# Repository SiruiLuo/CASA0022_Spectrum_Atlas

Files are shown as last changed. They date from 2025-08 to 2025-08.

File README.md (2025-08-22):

# 🌐 Spectrum Atlas - A Wireless Signal Detection & Visualization System

    

## 📖 Project Overview

Spectrum Atlas is a comprehensive wireless signal spectrum mapping and visualization system that integrates hardware and software technologies to generate 2D and 3D heatmaps of wireless signals in spatial environments, providing professional solutions for spectrum analysis, signal monitoring, and visualization applications.

<div align="center">

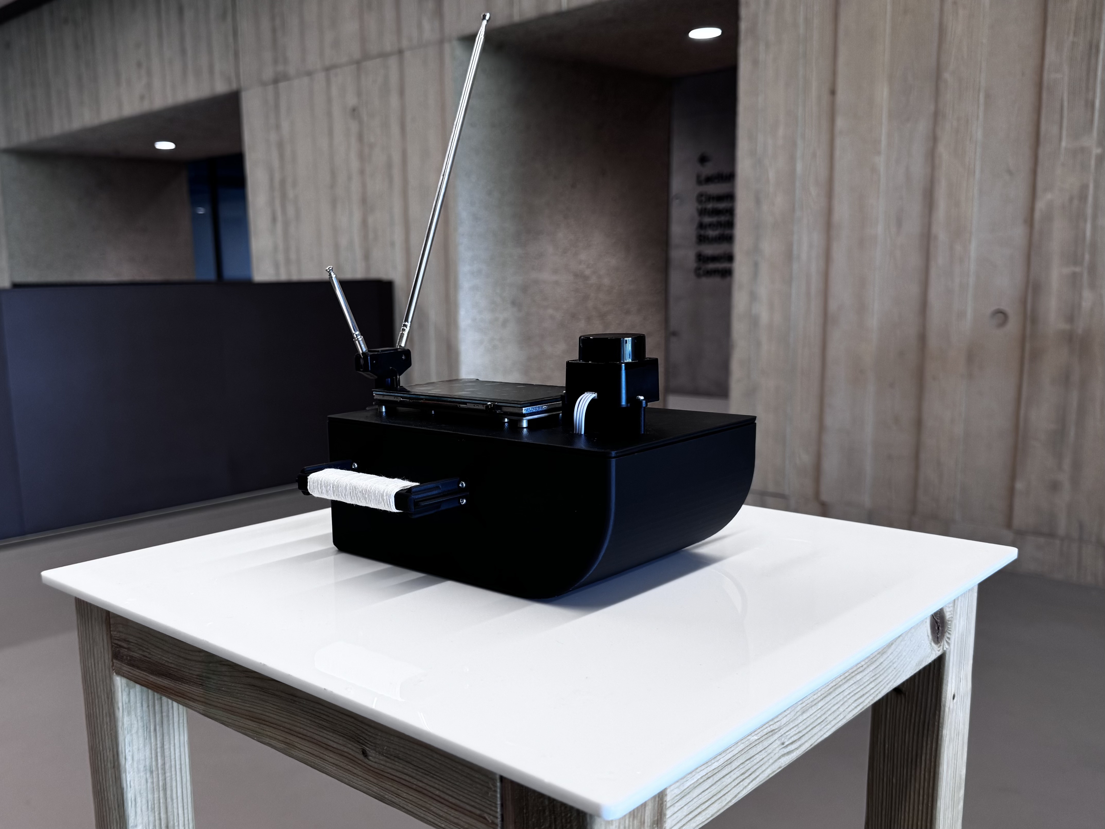
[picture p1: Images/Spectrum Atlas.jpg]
Spectrum Atlas System


**Figure 1: Spectrum Atlas System Overview**

</div>

### 🎥 Official Demo Video
<div align="center">



</div>

## ✨ Core Features

- 🎯 **Multi-band Signal Scanning**: Supports automatic scanning of multiple frequency bands from 27MHz to 1800MHz
- 📍 **Spatial Positioning**: Each sampling point contains precise 2D coordinate information
- 💾 **Data Persistence**: PostgreSQL database storage with multi-session management support
- 🗺️ **Heatmap Generation**: RBF interpolation + Gaussian filtering + visualization rendering
- 🔄 **Batch Processing**: Full frequency band batch output supporting multiple signal types
- 🌐 **Cross-device Collaboration**: Raspberry Pi generation → Local download viewing
- 🖥️ **Interactive Web Interface**: Real-time heatmap visualization with hover information display
- 📊 **Dynamic Data Loading**: Real-time database integration for live data access

## 🏗️ System Architecture

### Hardware Platform
- **Raspberry Pi 4 Model B**: Main control device responsible for running ROS, signal scanning, data storage, and image rendering
- **FHL-LD19 LiDAR**: For obtaining spatial shape and distance information, generating spatial maps, and 2D plane mapping construction
- **RTL-SDR Blog V4**: For acquiring signal strength (RSSI) at different frequency bands from 1 MHz to 1.78 GHz
- **Waveshare 5-inch Touch Display**: For graphical user interface display and user interaction

<div align="center">

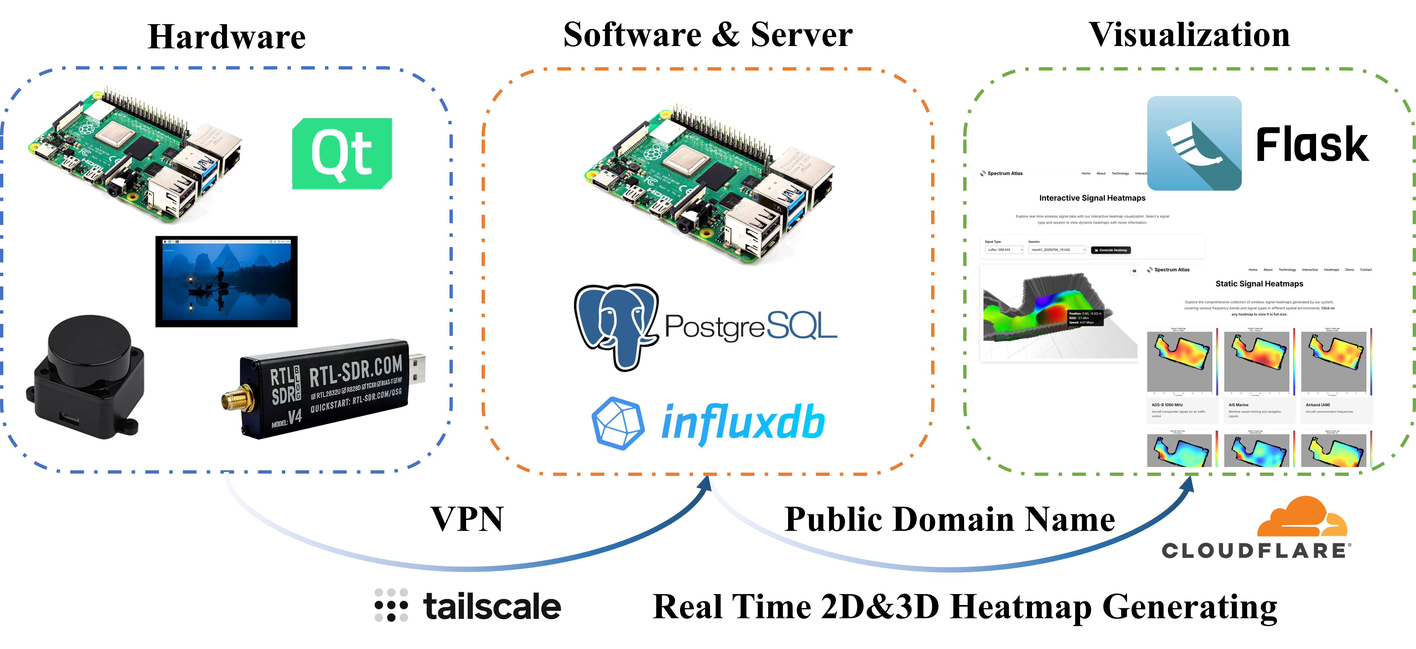
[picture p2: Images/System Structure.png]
System Structure


**Figure 2: System Architecture Structure**

</div>

### Software Architecture
- **ROS (Robot Operating System)**: Robot operating system for hardware control and data management
- **Qt GUI**: C++ desktop application providing user interaction interface
- **Flask Web Server**: Python web framework providing backend API services
- **PostgreSQL**: Relational database for signal data storage
- **LiDAR SLAM**: Uses Hector SLAM for environmental map construction

### Circuit Diagram
<div align="center">

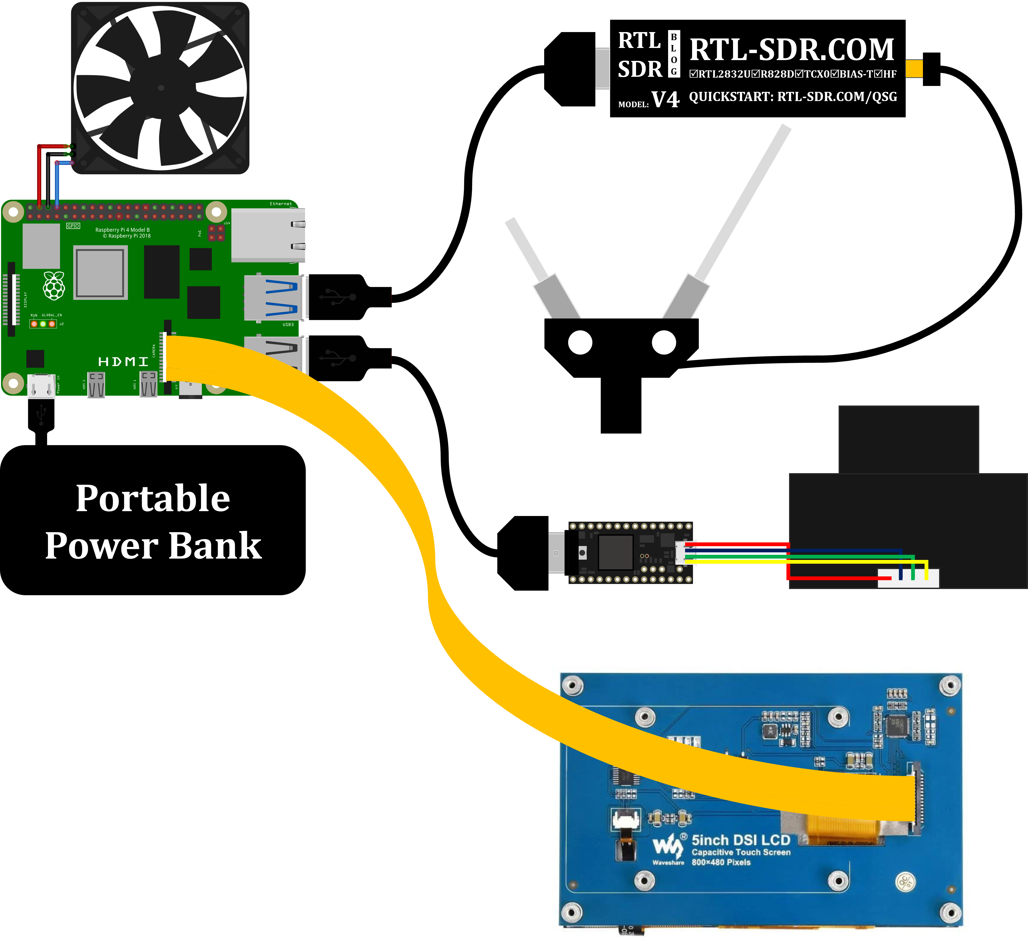
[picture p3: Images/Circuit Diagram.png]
Circuit Diagram


**Figure 3: System Circuit Diagram**

</div>

## 🔧 Technical Features

### Supported Signal Types
- **RC Low Band** (27-28 MHz): Toy remote control low frequency band
- **RC Aircraft** (35-36 MHz): UK RC aircraft dedicated frequency band
- **RC Ground** (40-41 MHz): UK RC car/boat remote control frequency band
- **TETRA / Emergency** (380-400 MHz): Police/fire/emergency communications
- **LoRa / ISM 433** (433-434 MHz): LoRa, RF remotes, access control
- **ISM 868** (868-870 MHz): LoRaWAN, Sigfox, NB-IoT, metering
- **GSM 900 UL** (880-915 MHz): User uplink channels (mobile device → base station)
- **GSM 900 DL** (925-960 MHz): Downlink channels (base station → mobile device)
- **FM Radio** (88-108 MHz): FM broadcast
- **Airband (AM)** (118-137 MHz): Pilot communications (AM)
- **AIS / Marine** (161-163 MHz): Maritime automatic identification system
- **ADS-B 1090** (1090 MHz): Aircraft broadcast position
- **LTE 1800** (1710-1760 MHz): LTE user uplink

### Algorithm Flow

#### Fixed-Parameter RBF-Gaussian Heatmap Algorithm (FPRGH) 
<div align="center">

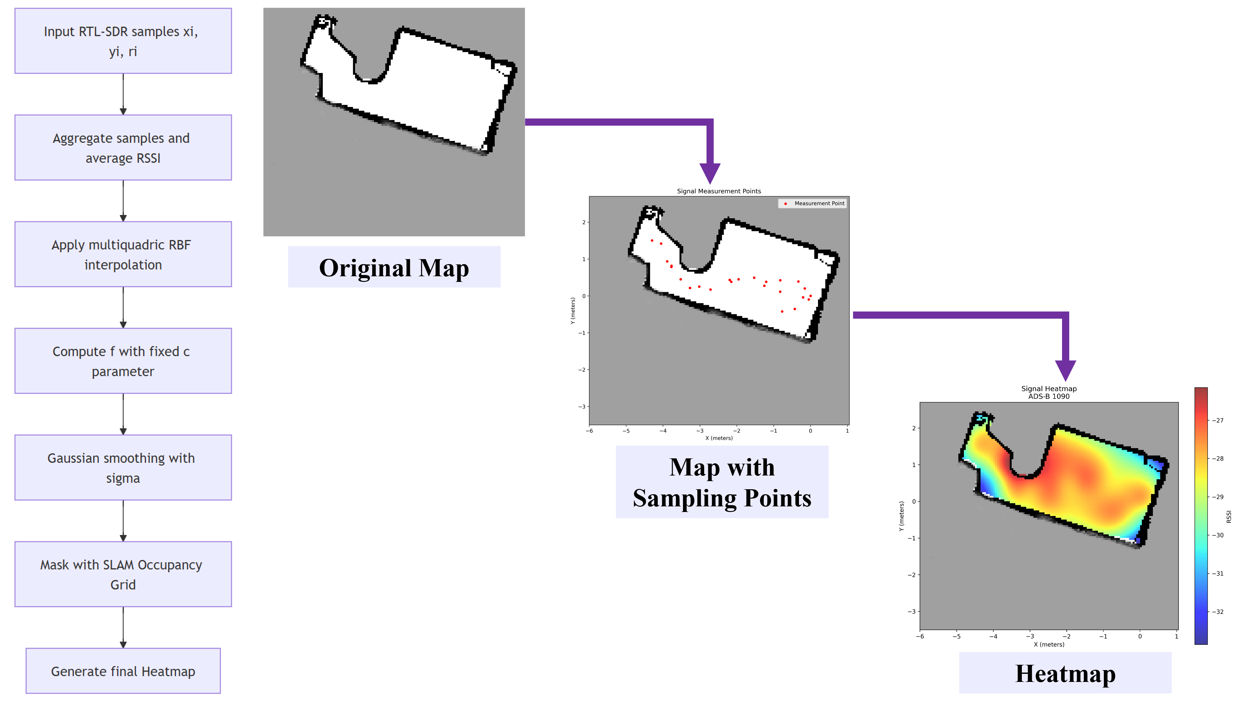
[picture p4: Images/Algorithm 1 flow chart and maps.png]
Algorithm 1


**Figure 4: Algorithm 1 - Map Construction and Data Acquisition**

</div>

#### Adaptive RBF Heatmap Algorithm with Spatial Scaling (ARH-SS)
<div align="center">

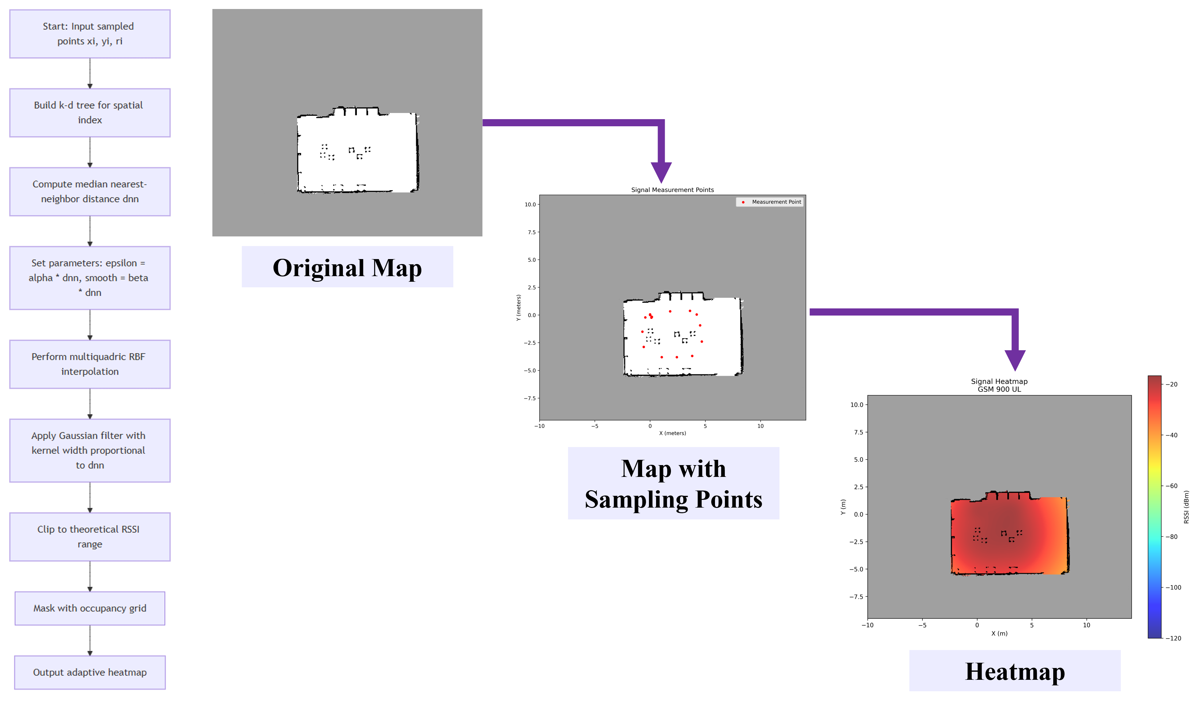
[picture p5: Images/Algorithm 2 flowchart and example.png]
Algorithm 2


**Figure 5: Algorithm 2 - Heatmap Generation and Visualization**

</div>

## 📁 Project Structure

```
CASA0022_Spectrum_Atlas/
├── 3D Models/                    # 3D printed model files
├── Detector/                     # Detector related code
│   ├── ble_scan.py              # BLE signal scanning
│   ├── ldlidar_ros_ws/         # LiDAR ROS workspace
│   └── ros_catkin_ws/          # ROS Catkin workspace
├── Spectrum_Atlas_GUI/          # Qt GUI application
├── Server and Database/         # Server and database
│   ├── Database/               # Database scripts and API
│   └── Flask Server/           # Flask web server
├── Wireless Signal Dataset/     # Wireless signal dataset
└── Images/                     # Project images and charts
```

## 🚀 Quick Start

### Requirements
- **Operating System**: Ubuntu 18.04+ / Raspberry Pi OS
- **Python**: 3.8+
- **ROS**: Melodic (recommended)
- **Qt**: 5.12+
- **Database**: PostgreSQL 12+

### Installation Steps

1. **Clone the Project**
```bash
git clone https://github.com/SiruiLuo/CASA0022_Spectrum_Atlas.git
cd CASA0022_Spectrum_Atlas
```

2. **Install ROS Dependencies**
```bash
# Install ROS Melodic
sudo apt update
sudo apt install ros-melodic-desktop-full

# Initialize ROS workspace
cd Detector/ros_catkin_ws
catkin_make
source devel/setup.bash
```

3. **Install Python Dependencies**
```bash
cd Server and Database/Flask Server/Spectrum_Atlas_Webpage-main
python -m venv spectrum_env
source spectrum_env/bin/activate  # Linux/Mac
# or
spectrum_env\Scripts\activate     # Windows

pip install -r requirements.txt
```

4. **Configure Database**
```bash
# Install PostgreSQL
sudo apt install postgresql postgresql-contrib

# Create database and user
sudo -u postgres psql
CREATE DATABASE spectrum_atlas;
CREATE USER spectrum_user WITH PASSWORD 'your_password';
GRANT ALL PRIVILEGES ON DATABASE spectrum_atlas TO spectrum_user;
\q
```

5. **Compile Qt Application**
```bash
cd Spectrum_Atlas_GUI
qmake
make
```

## 📊 Usage Examples

### Signal Acquisition
The system can automatically scan multiple frequency bands and generate heatmaps:

#### Student Dormitory Signal Heatmaps (2025-07-09)
All frequency band heatmaps generated from student dorm collection:

**Low Frequency Bands:**

<div align="center">

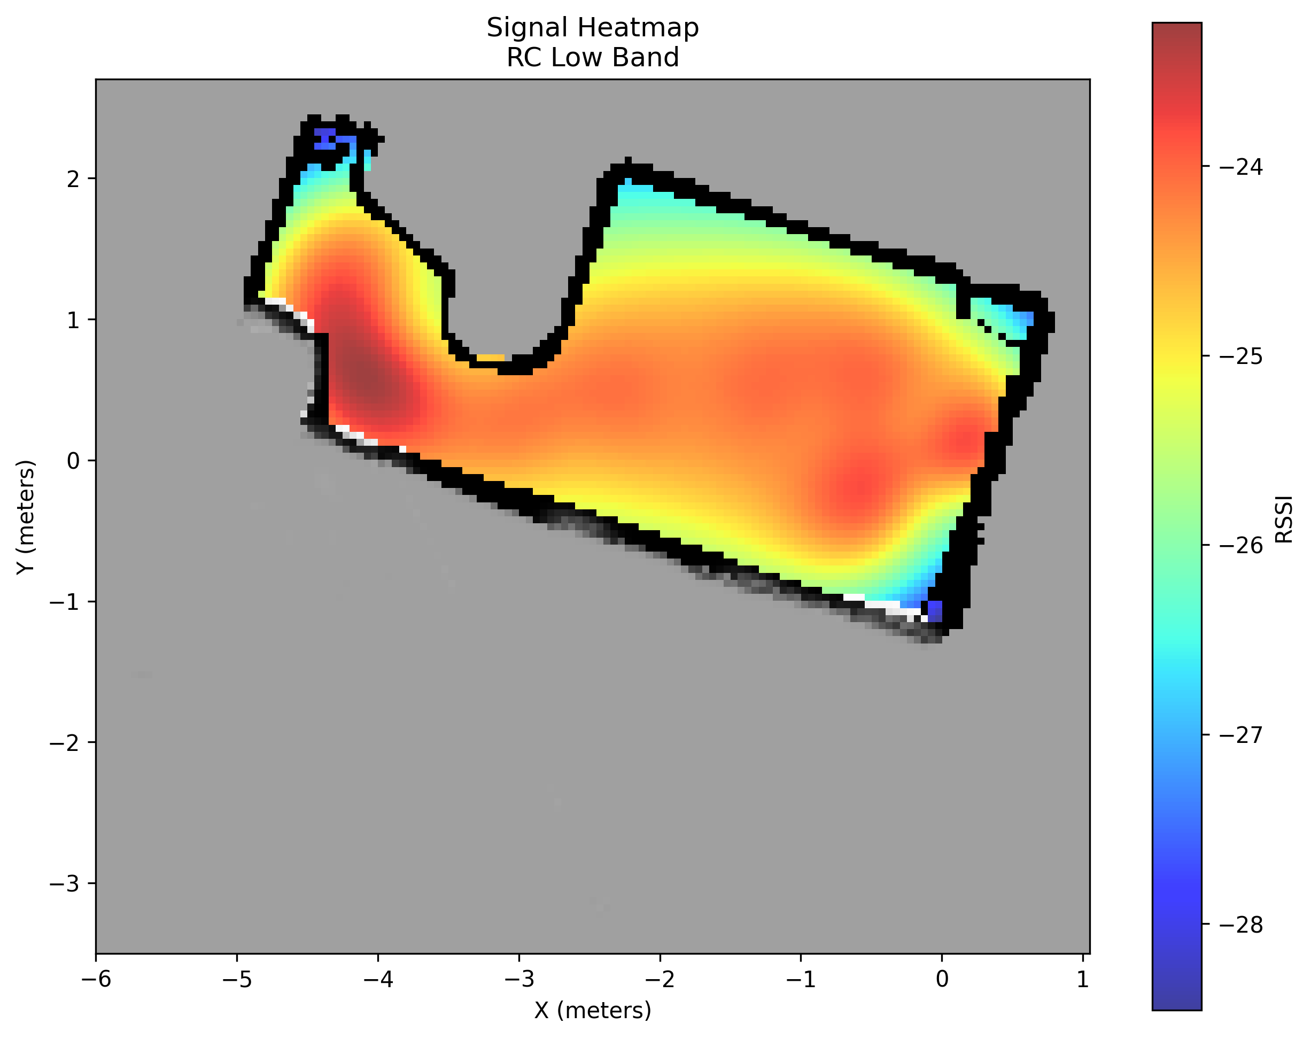
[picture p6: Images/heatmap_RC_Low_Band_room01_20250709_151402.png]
RC Low Band
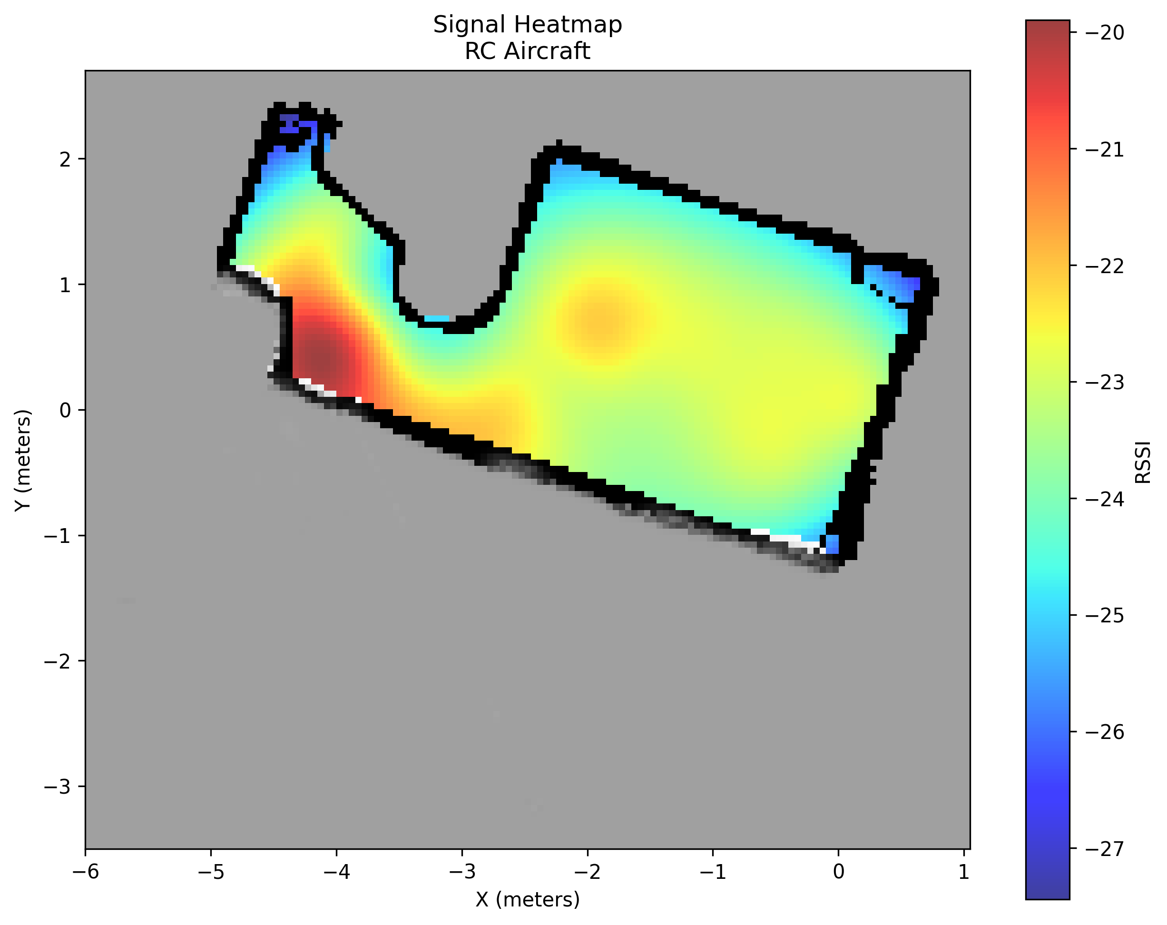
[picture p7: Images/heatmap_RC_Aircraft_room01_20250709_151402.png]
RC Aircraft
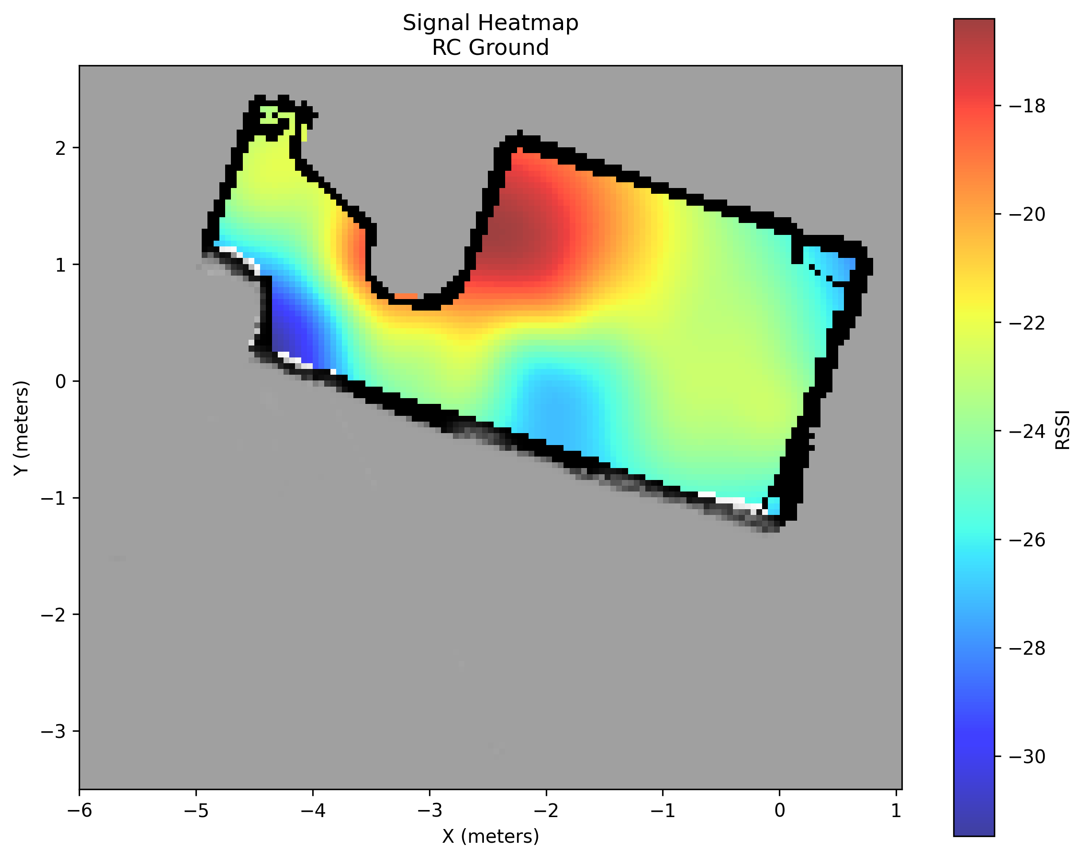
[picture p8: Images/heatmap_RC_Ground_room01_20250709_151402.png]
RC Ground
  

</div>

**Medium Frequency Bands:**

<div align="center">

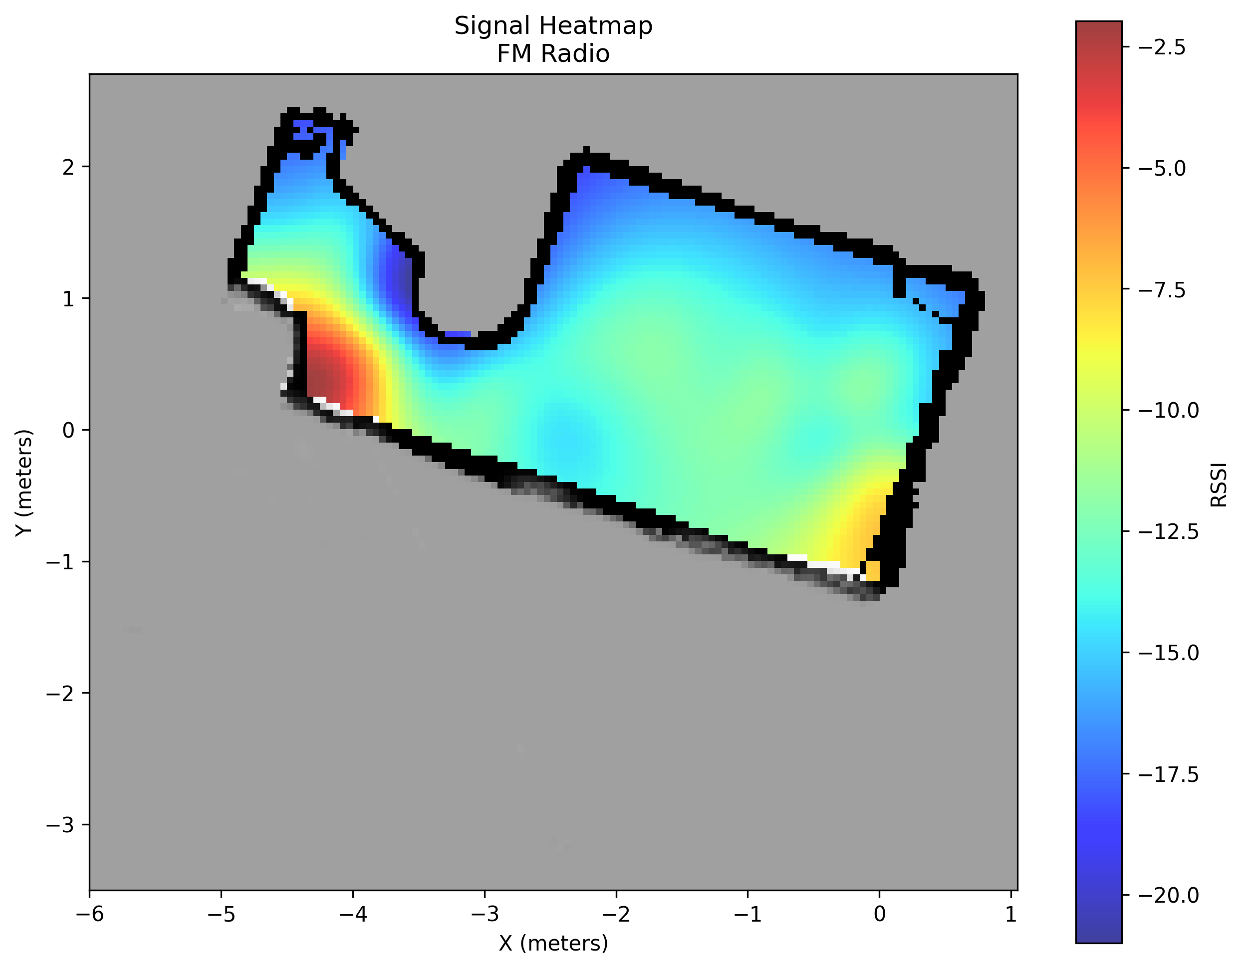
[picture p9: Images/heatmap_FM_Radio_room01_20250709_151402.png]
FM Radio
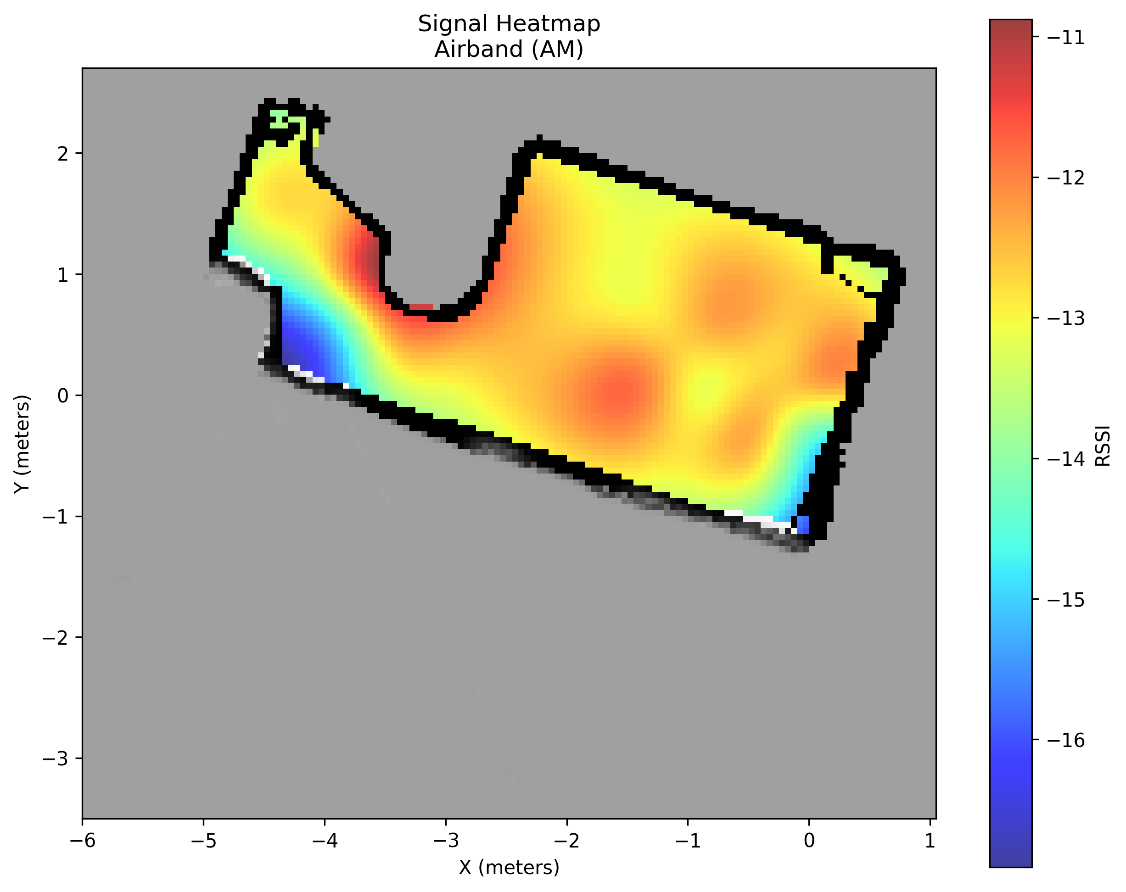
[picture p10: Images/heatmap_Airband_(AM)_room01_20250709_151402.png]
Airband AM
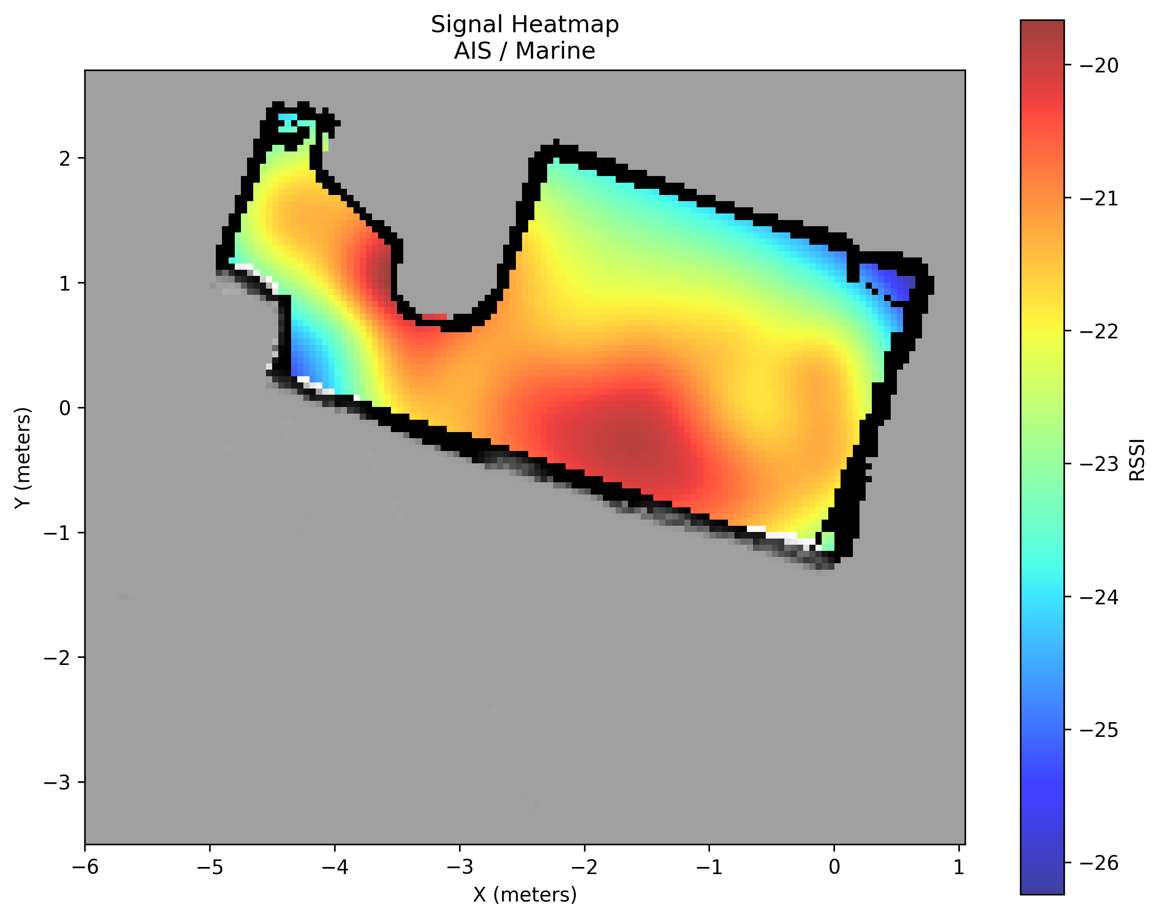
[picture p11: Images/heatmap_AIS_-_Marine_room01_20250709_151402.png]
AIS Marine
  

</div>

**High Frequency Bands:**

<div align="center">

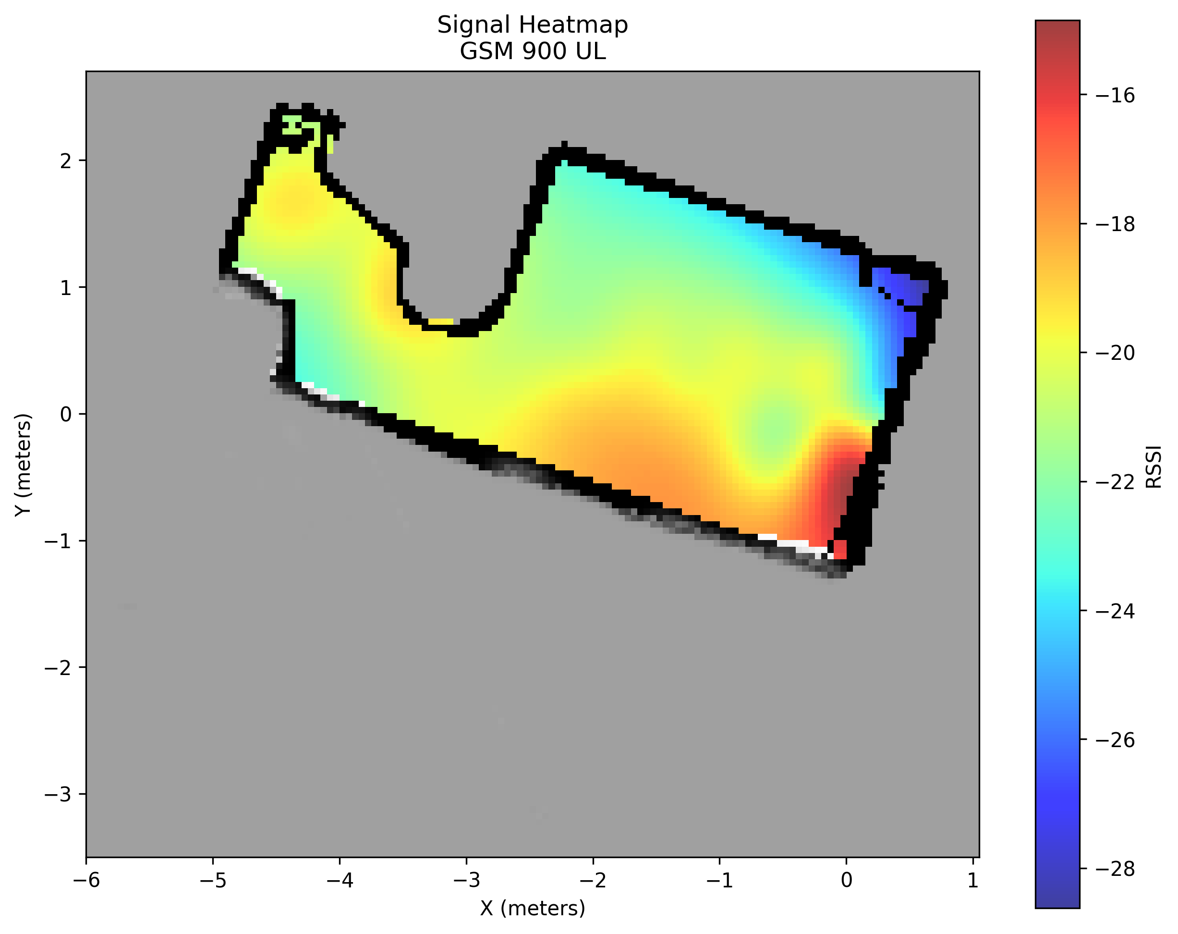
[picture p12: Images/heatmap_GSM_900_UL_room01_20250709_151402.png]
GSM 900 UL
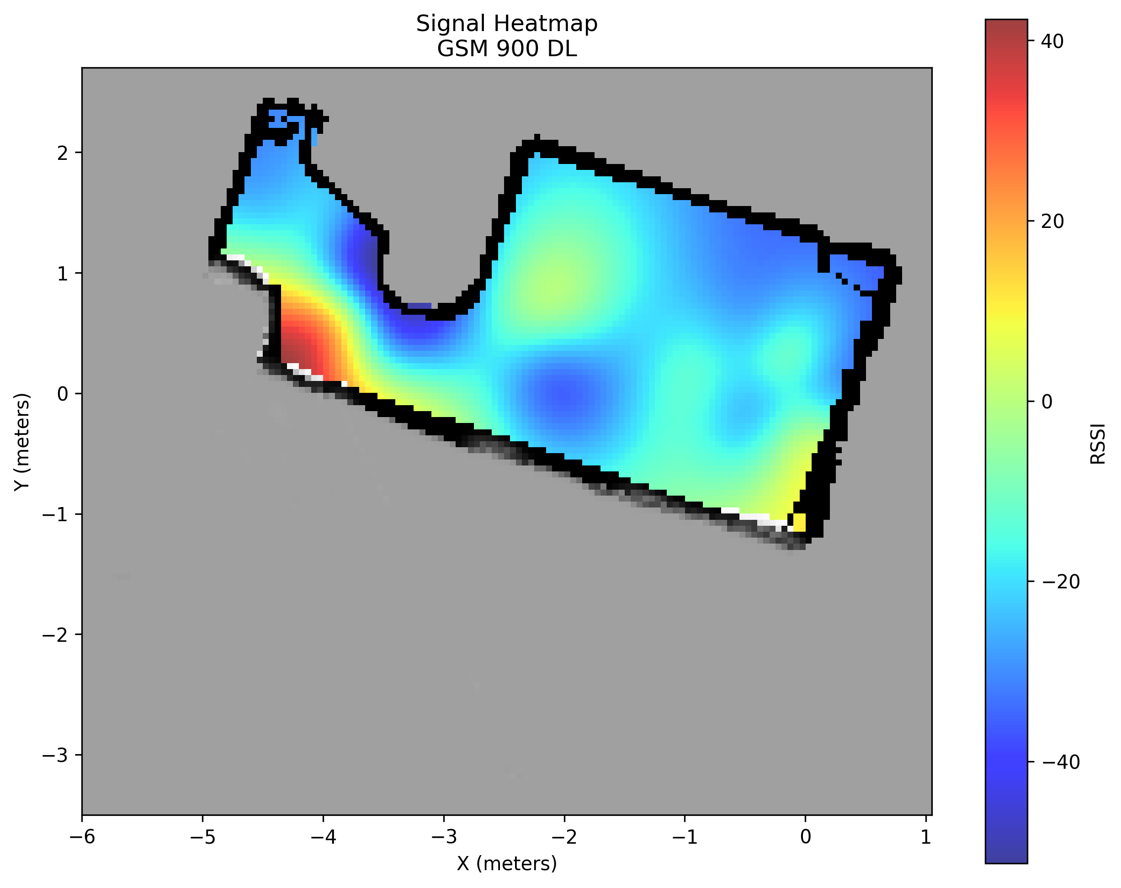
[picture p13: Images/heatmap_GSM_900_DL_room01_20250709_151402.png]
GSM 900 DL
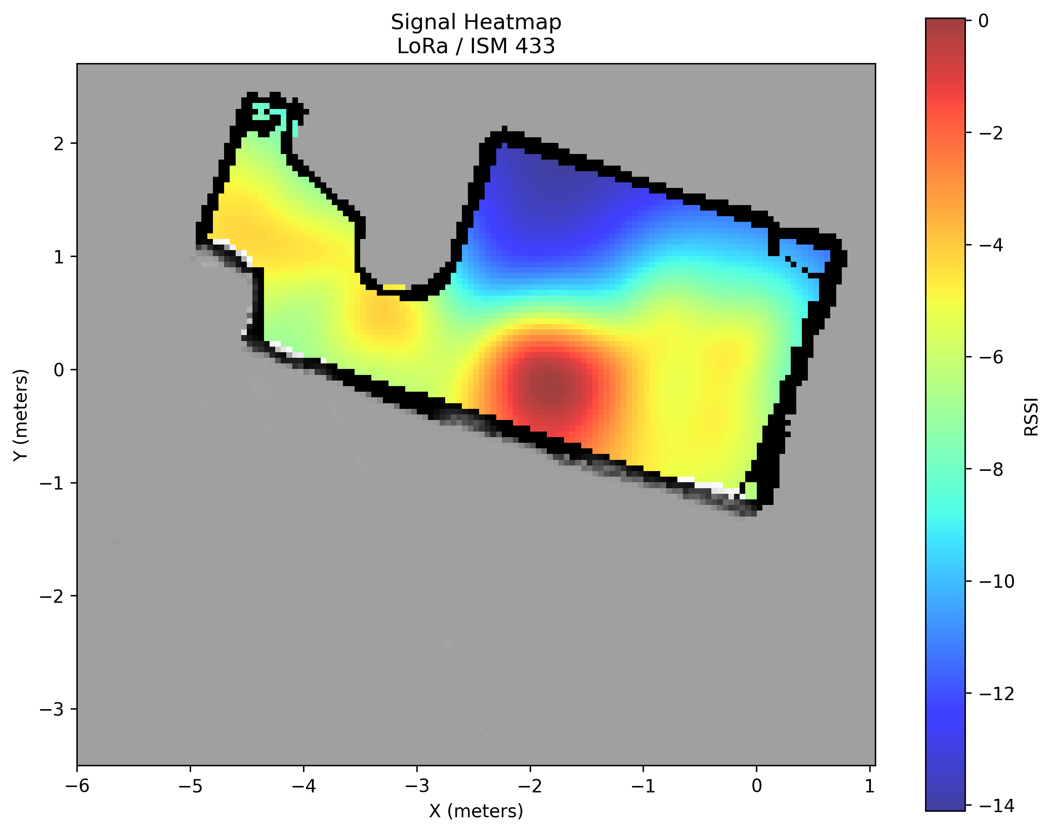
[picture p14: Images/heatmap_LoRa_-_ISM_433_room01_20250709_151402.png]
LoRa ISM 433
  

</div>

**Ultra High Frequency Bands:**

<div align="center">

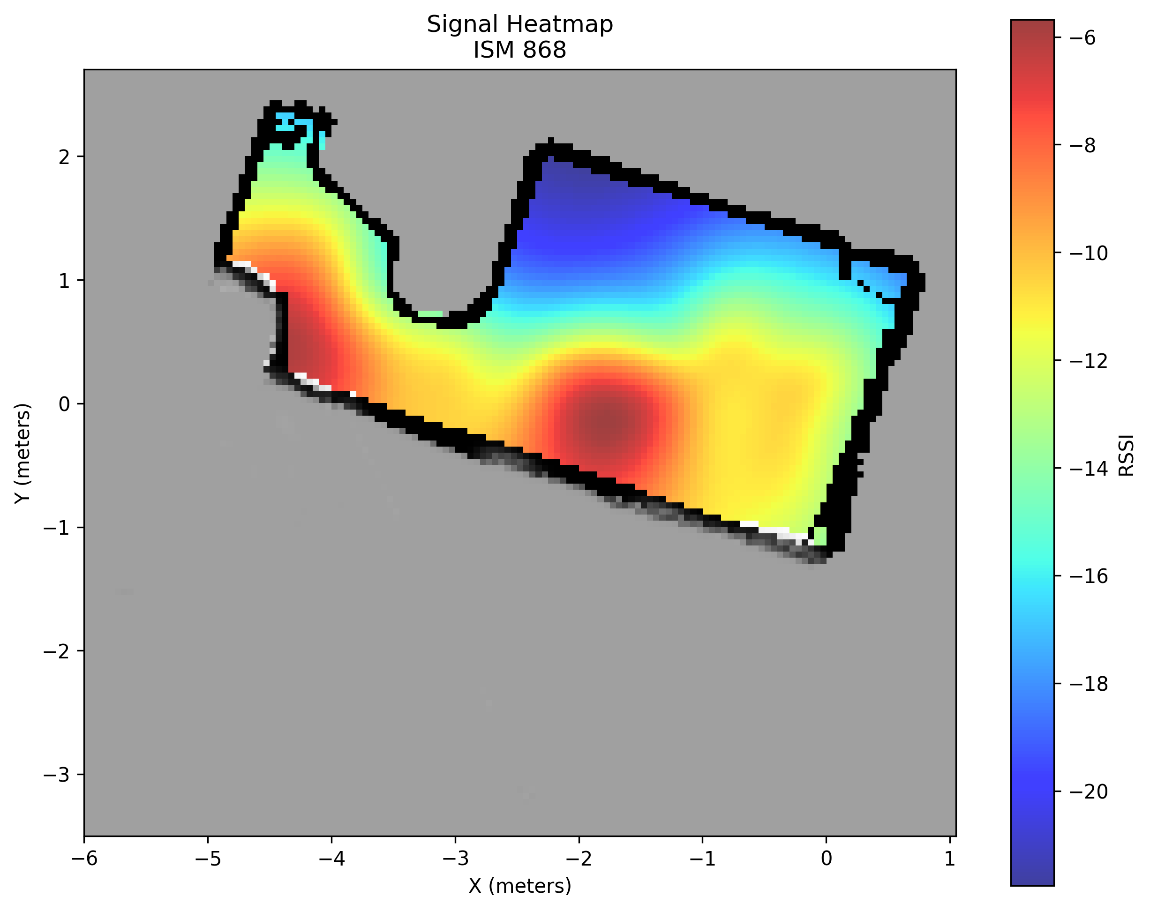
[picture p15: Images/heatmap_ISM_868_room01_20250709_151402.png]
ISM 868
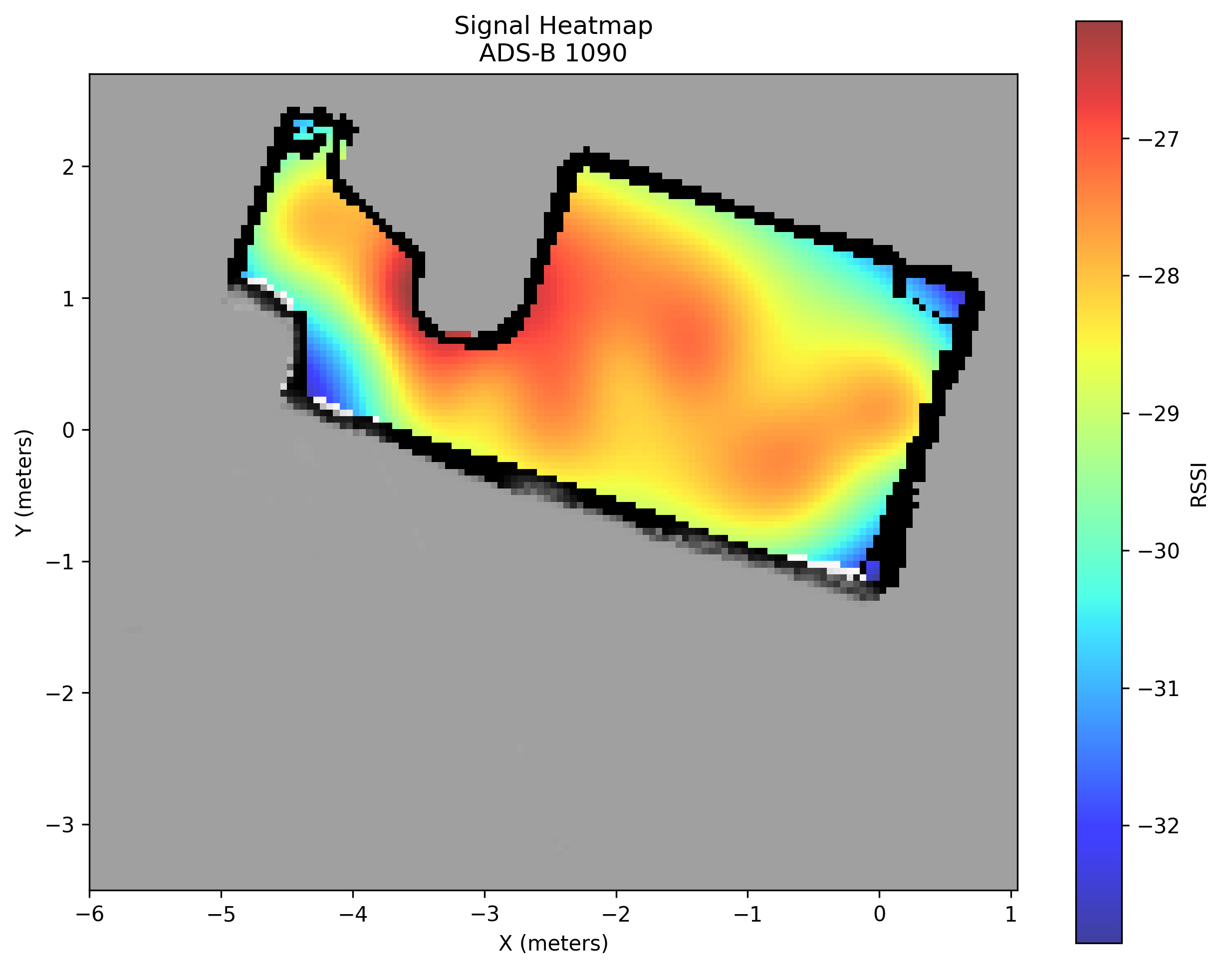
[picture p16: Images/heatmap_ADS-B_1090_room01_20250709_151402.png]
ADS-B 1090
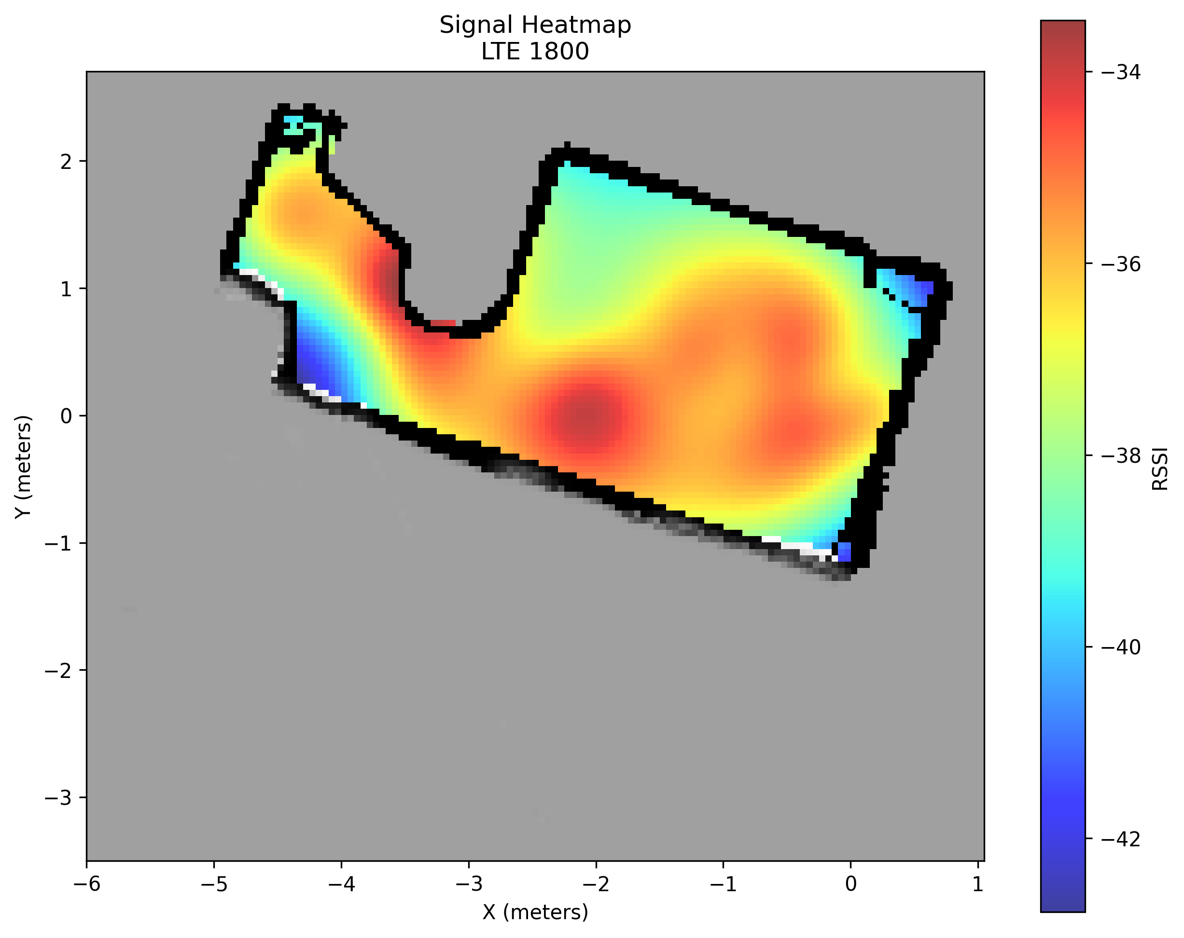
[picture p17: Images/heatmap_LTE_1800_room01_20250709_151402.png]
LTE 1800
  

</div>

**Emergency & Special Bands:**

<div align="center">

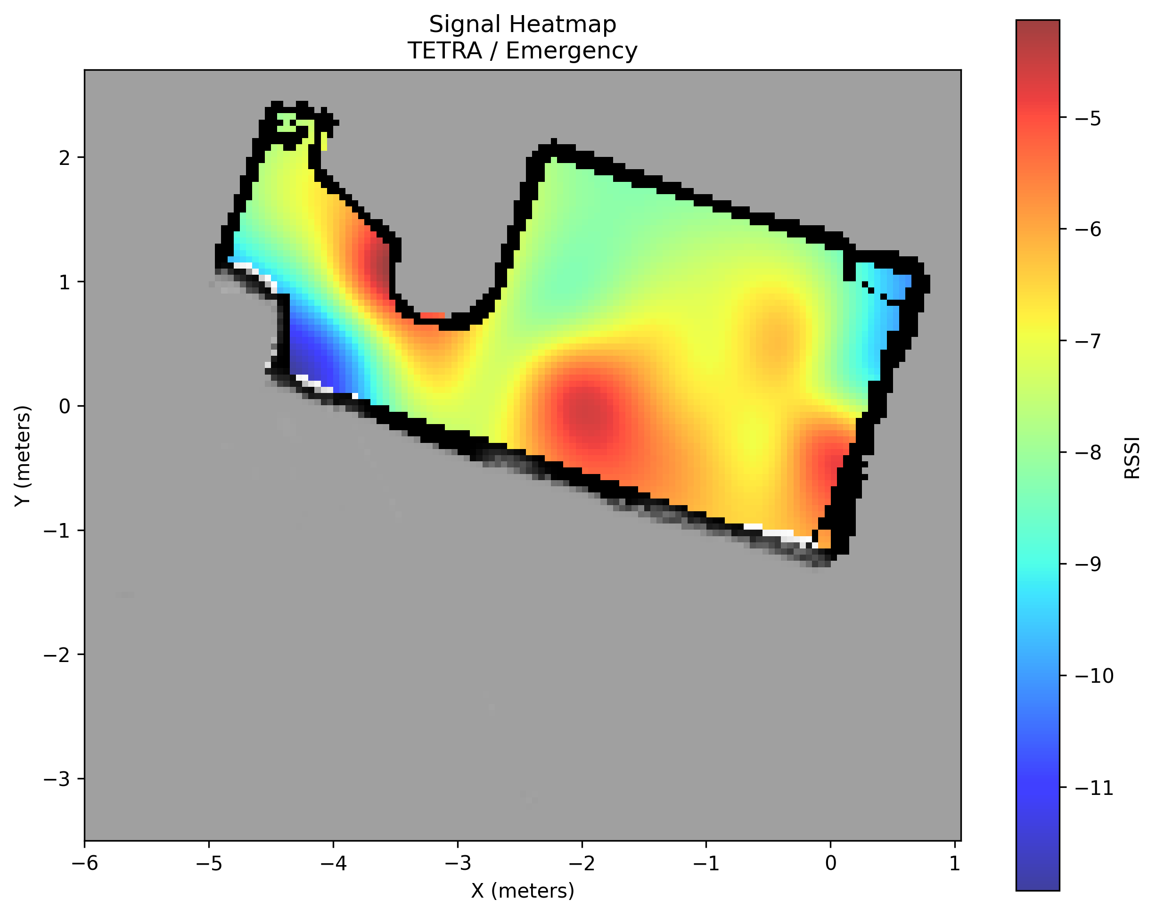
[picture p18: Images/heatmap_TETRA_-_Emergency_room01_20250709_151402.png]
TETRA Emergency


</div>

### BLE Signal Analysis Results
**BLE RSSI Analysis Dashboard:**

<div align="center">

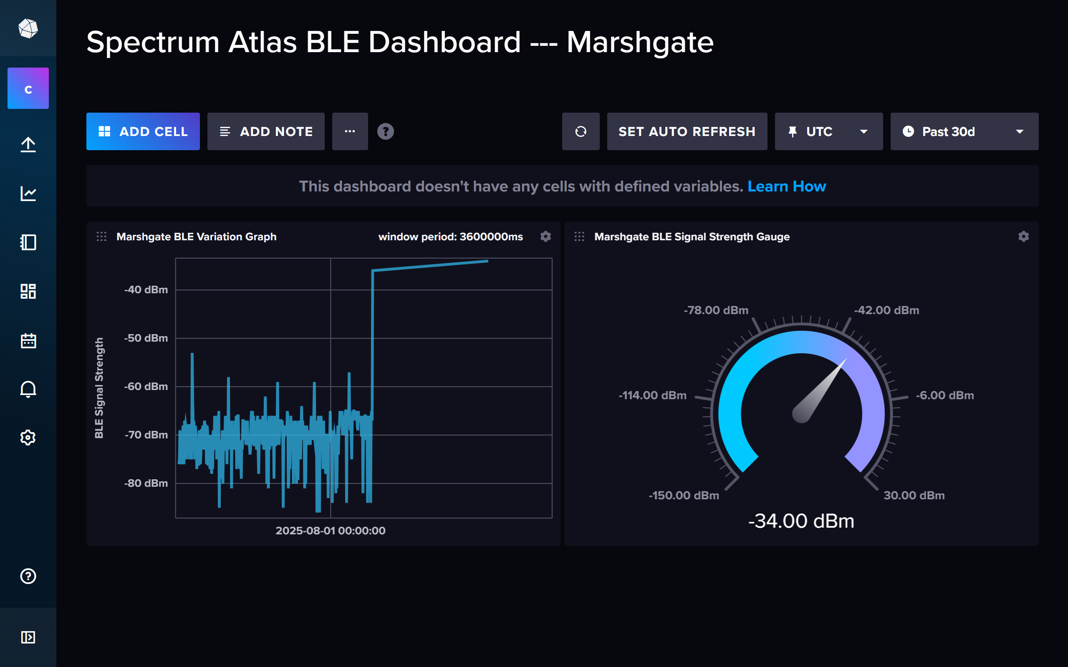
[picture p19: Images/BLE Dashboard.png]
BLE Dashboard


**Figure 16: BLE Signal Analysis Dashboard**

</div>

**BLE RSSI Variation Analysis:**

<div align="center">

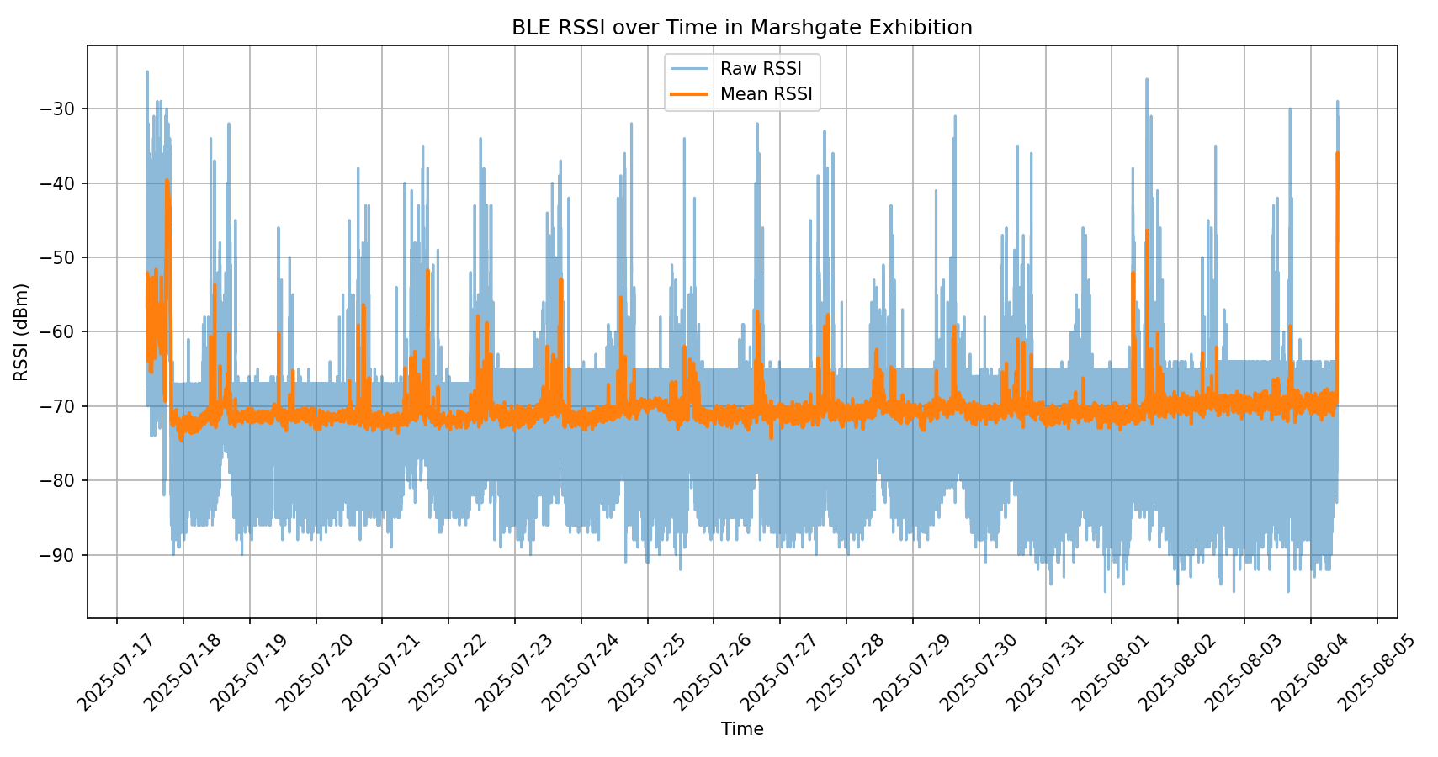
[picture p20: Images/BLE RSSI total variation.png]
BLE RSSI Variation
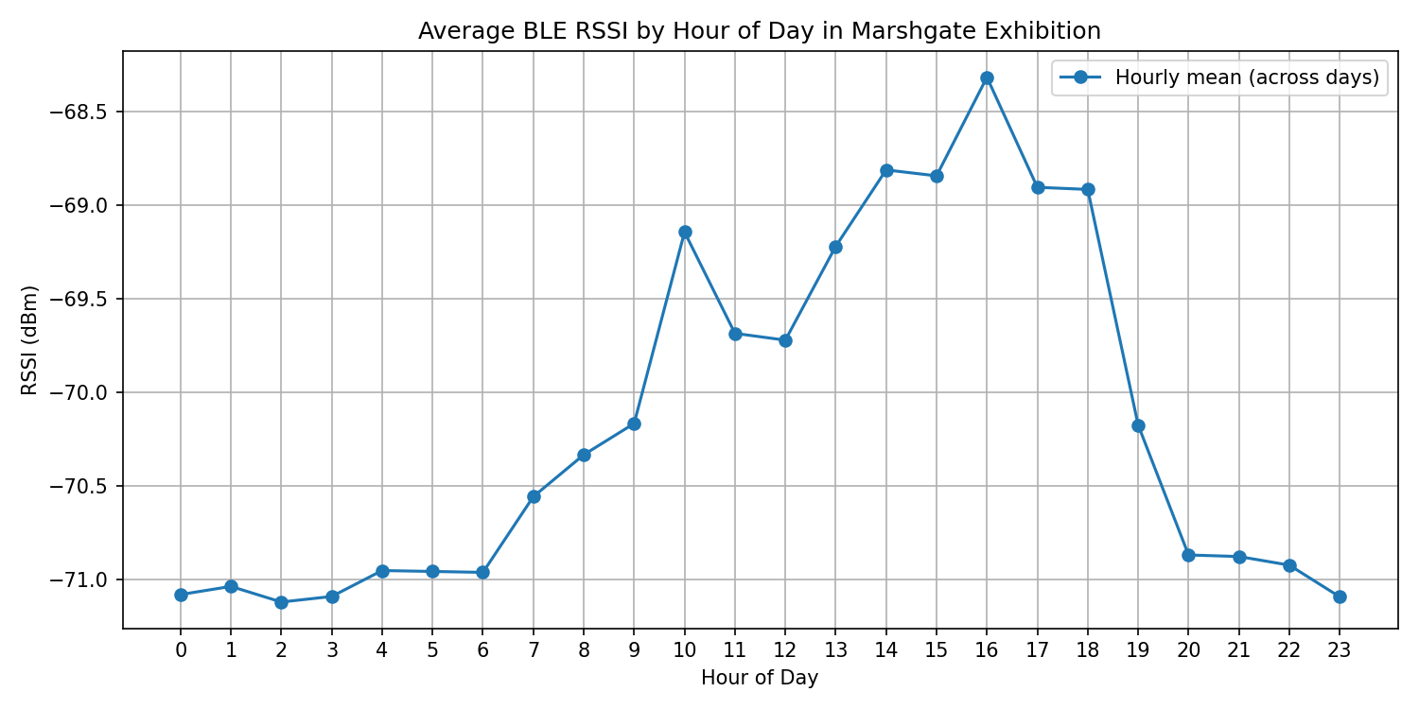
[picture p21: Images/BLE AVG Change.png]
BLE Average Change
 

**Figure 17: BLE RSSI Total Variation and Average Change Analysis**

</div>

### GUI Interface
<div align="center">

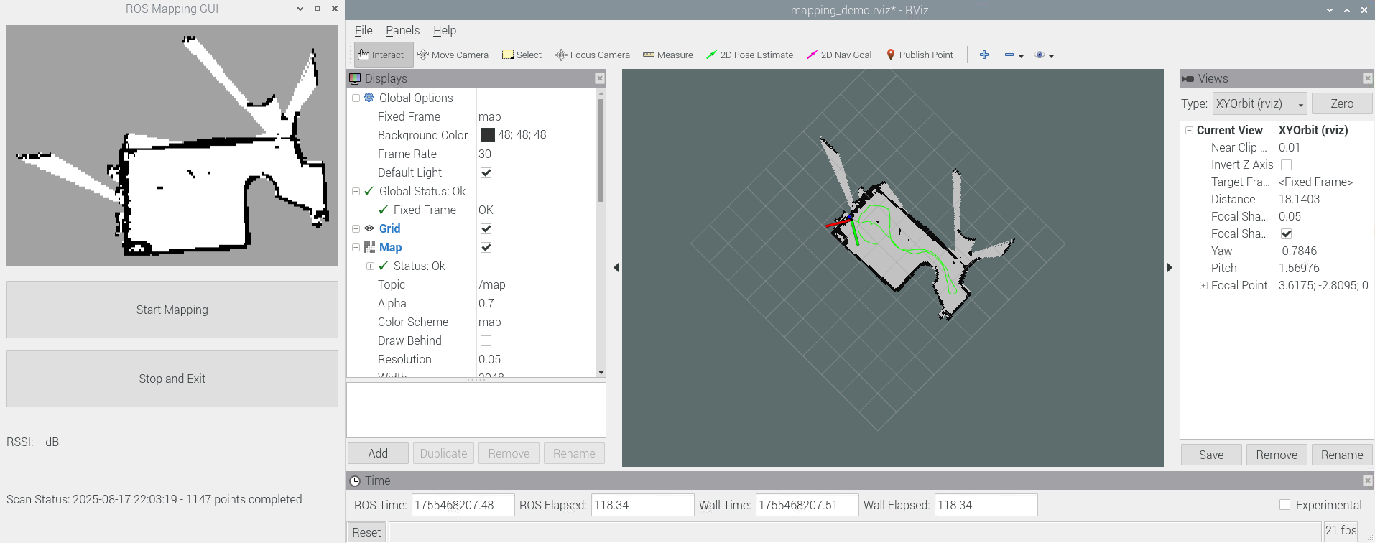
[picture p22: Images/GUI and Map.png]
GUI and Map


**Figure 6: GUI Interface and Map Display**

</div>

### System Deployment
<div align="center">

Deployment in Exhibition

**Figure 7: System Deployment in Exhibition**

</div>

## 🔍 Data Acquisition Process

### Sampling Flowchart
<div align="center">

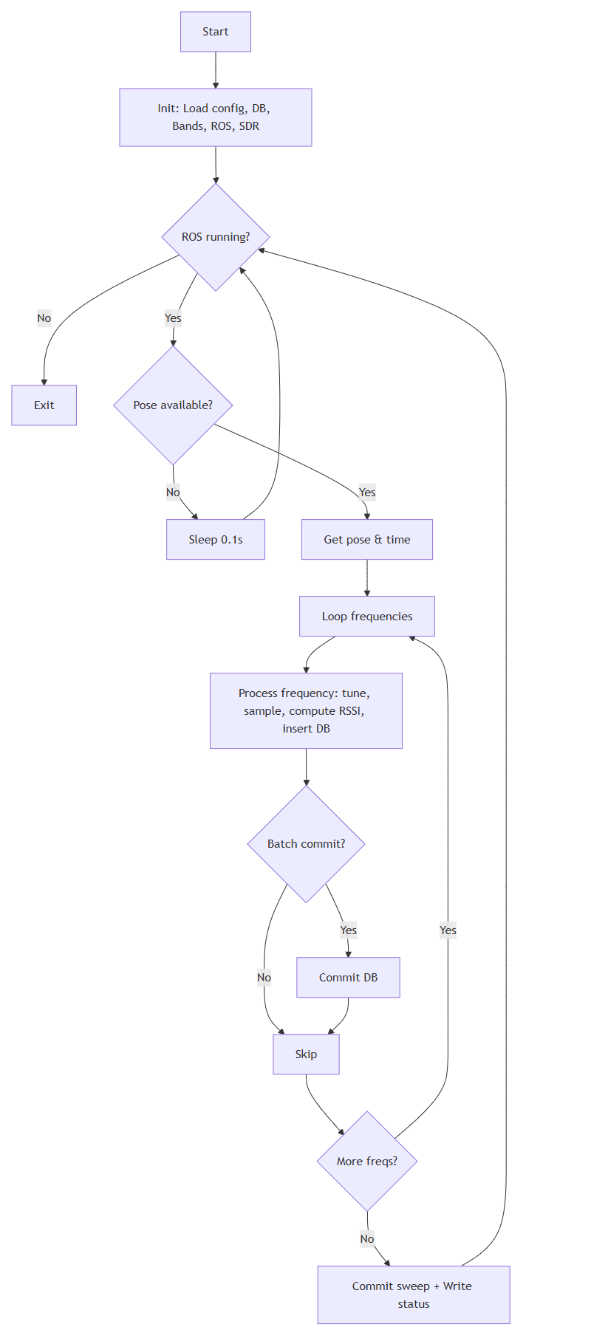
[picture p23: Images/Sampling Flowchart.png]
Sampling Flowchart


**Figure 8: Data Sampling Flowchart**

</div>

### Data Acquisition Commands and Data
<div align="center">

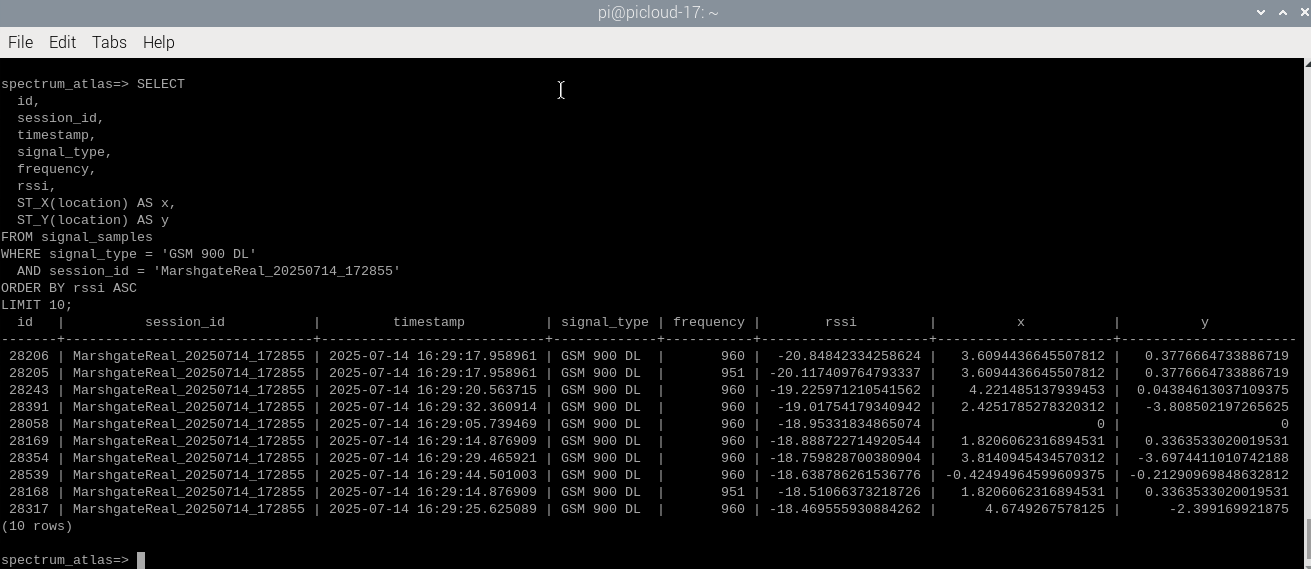
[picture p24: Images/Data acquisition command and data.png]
Data Acquisition


**Figure 9: Data Acquisition Commands and Data**

</div>

## 🗺️ Map Generation

### Hector SLAM Topics
LiDAR topics available in Hector SLAM:

<div align="center">

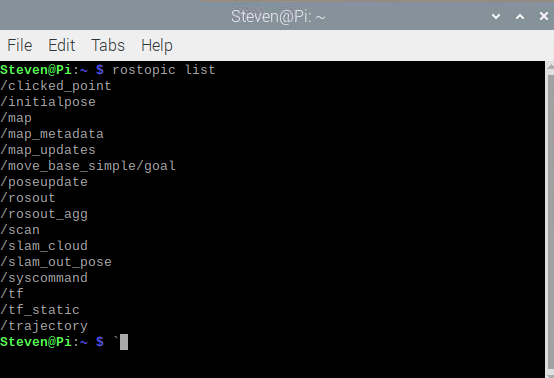
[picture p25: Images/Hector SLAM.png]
Hector SLAM


**Figure 10: Hector SLAM Mapping**

</div>

### Rviz Example
<div align="center">

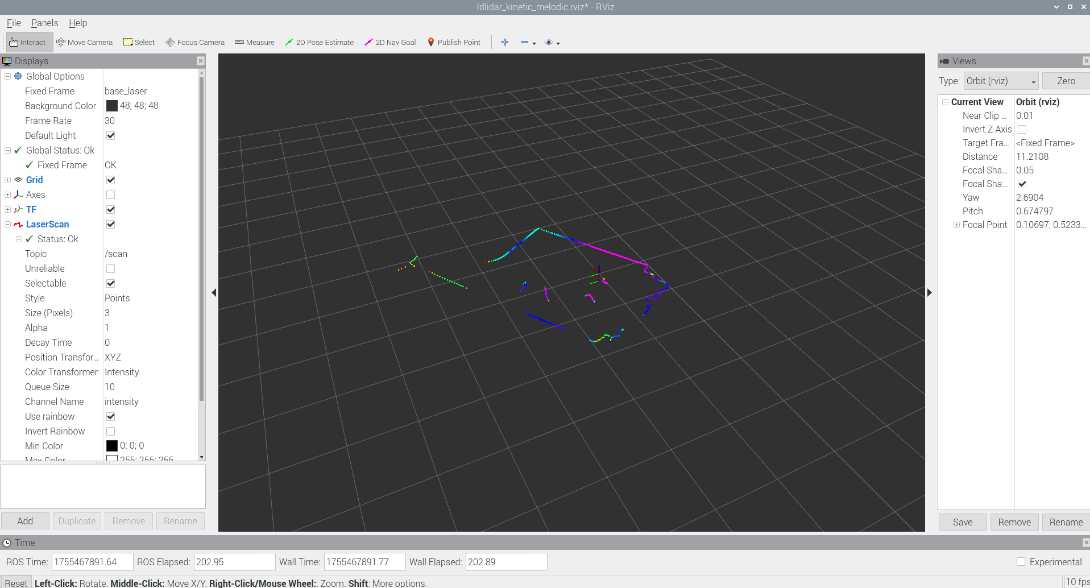
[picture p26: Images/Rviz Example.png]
Rviz Example


**Figure 11: Rviz Visualization Example**

</div>

## 💻 Web Application Features

### Interactive Heatmap Visualization
- **Real-time Data Loading**: Connects to PostgreSQL database for live signal data
- **Interactive Controls**: Dynamically select signal types and sessions
- **Hover Information**: Display signal strength and position coordinates on mouse hover
- **Professional UI**: Modern, clean interface with consistent styling

### Flask Interface
<div align="center">

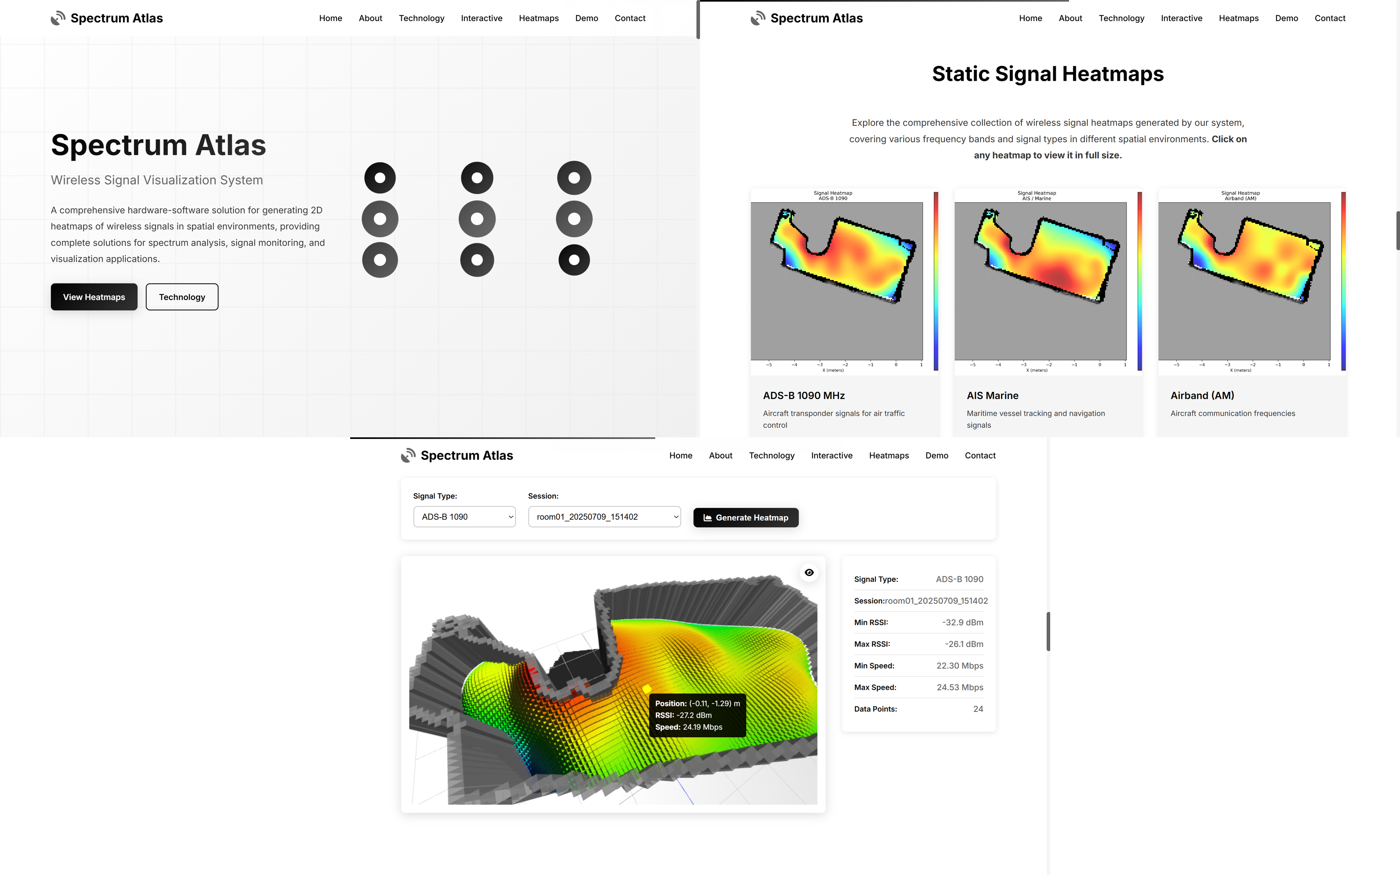
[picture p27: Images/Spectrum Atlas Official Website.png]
Spectrum Atlas Official Website


**Figure 12: Spectrum Atlas Official Website**

</div>

## 🔧 Hardware Components

### Main Components
- **RTL-SDR Receiver**: For signal reception and analysis
- **LiDAR Sensor**: For environmental map construction
- **Antenna System**: For signal reception
- **Display Module**: Waveshare display screen
- **Cooling System**: Fan and heat sink

### 3D Printed Enclosure
The project includes complete 3D printed enclosure design:

#### Main Box
<div align="center">

Box

**Figure 13: 3D Printed Main Box**

</div>

#### Lid Cover
<div align="center">

Lid

**Figure 14: 3D Printed Lid Cover**

</div>

#### Handle Components
<div align="center">

Handles

**Figure 15: 3D Printed Handle Components**

</div>

## 📈 Performance Metrics

- **Scanning Frequency**: Supports full frequency band scanning from 27MHz to 1800MHz
- **Positioning Accuracy**: Centimeter-level positioning accuracy based on LiDAR
- **Data Update Rate**: Real-time data acquisition and visualization
- **Storage Capacity**: Supports TB-level data storage
- **Concurrent Users**: Web interface supports multiple users accessing simultaneously

## 📞 Contact

- **Project Maintainer**: [Sirui Luo]
- **Email**: [sirui.luo.24@ucl.ac.uk]

## 🙏 Acknowledgments

Thanks to the following open source projects and communities for their support:
- [ROS (Robot Operating System)](https://www.ros.org/)
- [RTL-SDR](https://www.rtl-sdr.com/)
- [Qt Framework](https://www.qt.io/)
- [Flask](https://flask.palletsprojects.com/)
- [PostgreSQL](https://www.postgresql.org/)

---

⭐ If this project is helpful to you, please give me a star!

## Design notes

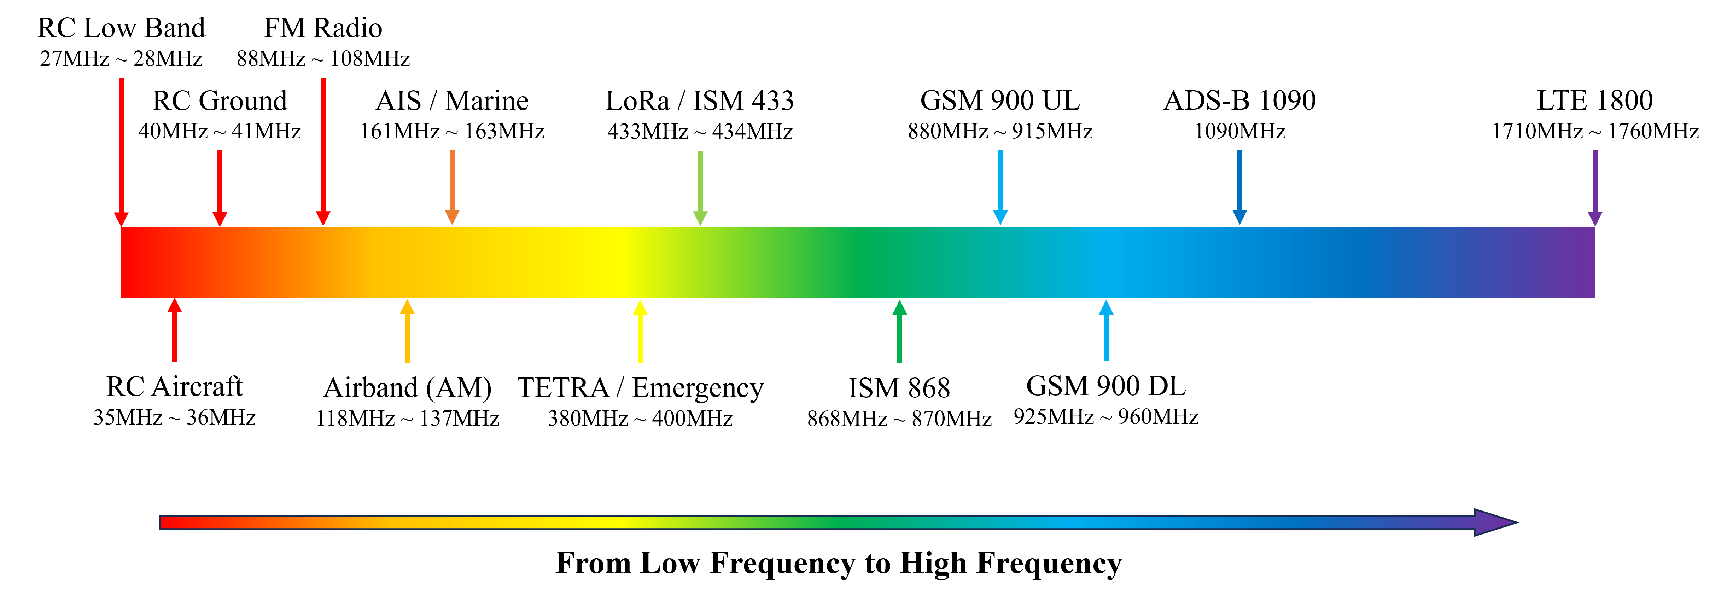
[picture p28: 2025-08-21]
Images/Spectrum Map.png

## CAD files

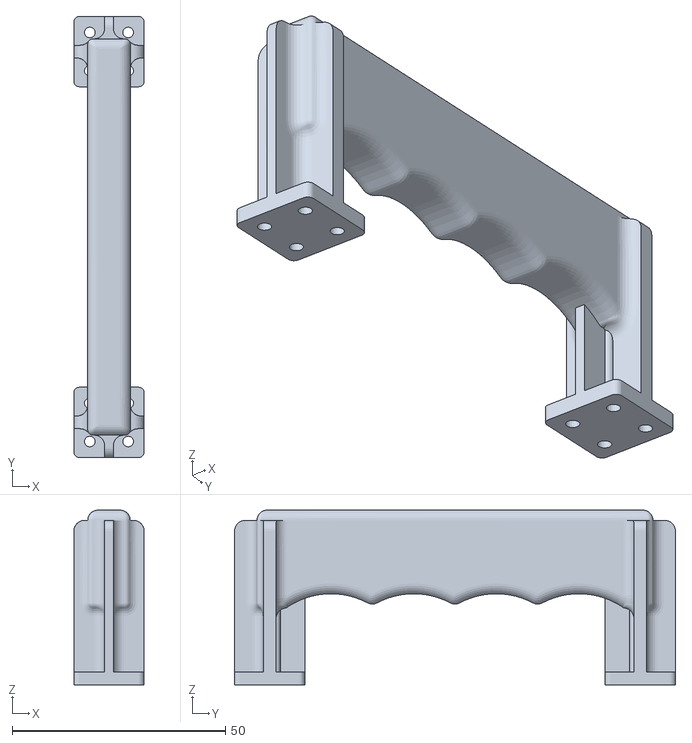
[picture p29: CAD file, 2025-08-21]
3D Models/The Handle.stl
16.5 x 103.5 x 41.0

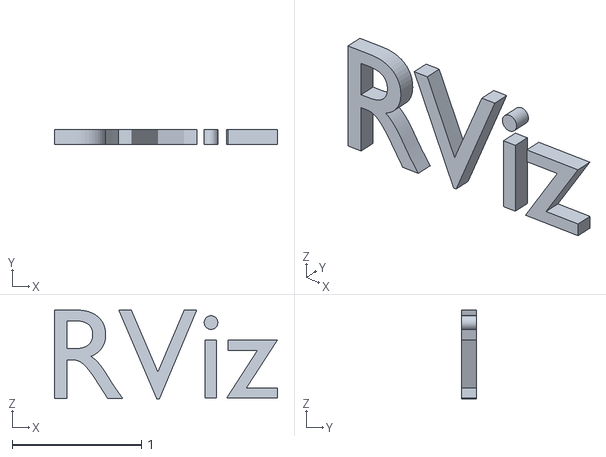
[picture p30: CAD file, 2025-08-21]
Detector/ros_catkin_ws/src/rviz/image_src/RViz.stl
1.72 x 0.115 x 0.688

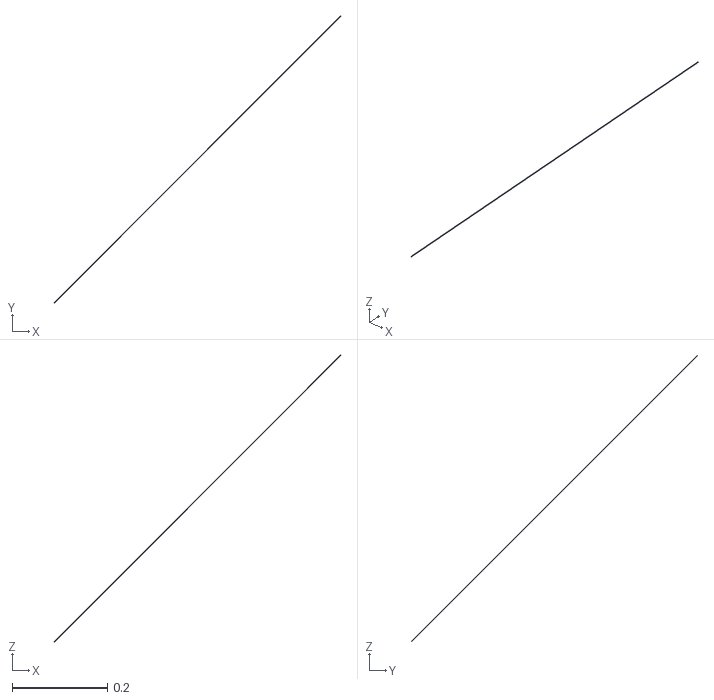
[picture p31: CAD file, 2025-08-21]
Detector/ros_catkin_ws/src/rviz/src/test/meshes/valid.stl
0.6 x 0.6 x 0.6

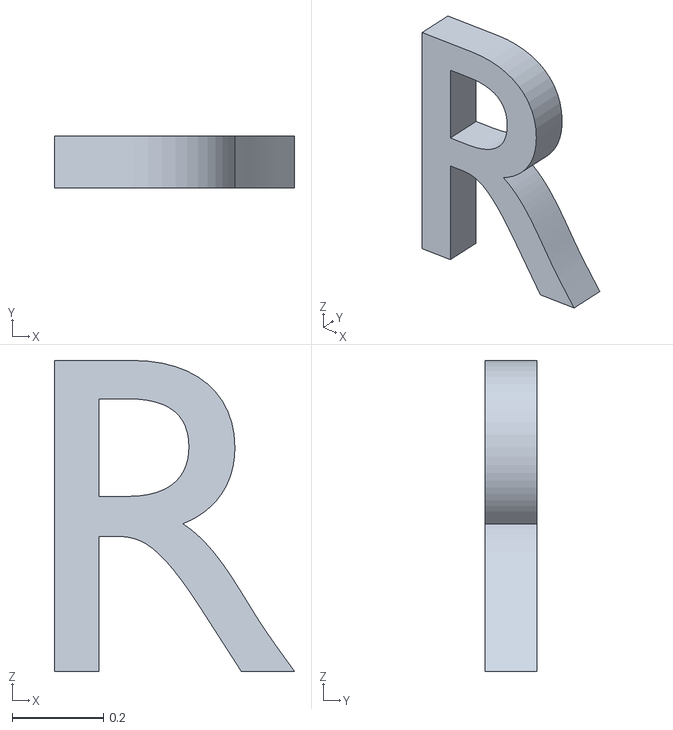
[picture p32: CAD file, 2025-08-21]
Detector/ros_catkin_ws/src/rviz/image_src/R.stl
0.527 x 0.115 x 0.682

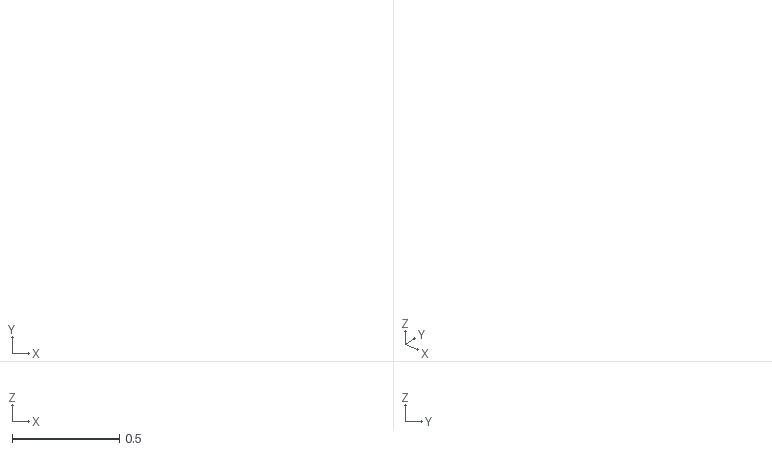
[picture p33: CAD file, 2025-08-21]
Detector/ros_catkin_ws/src/rviz/src/test/meshes/invalid_end_tags.stl
1.50 x 0.15 x 0.015

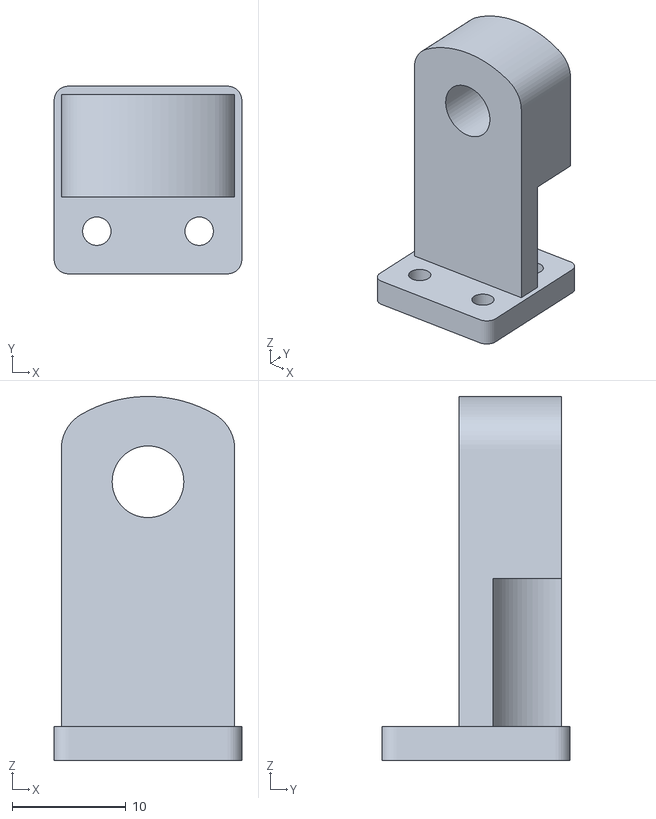
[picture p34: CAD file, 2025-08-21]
3D Models/The Antenna Connector.stl
16.5 x 16.5 x 32.0

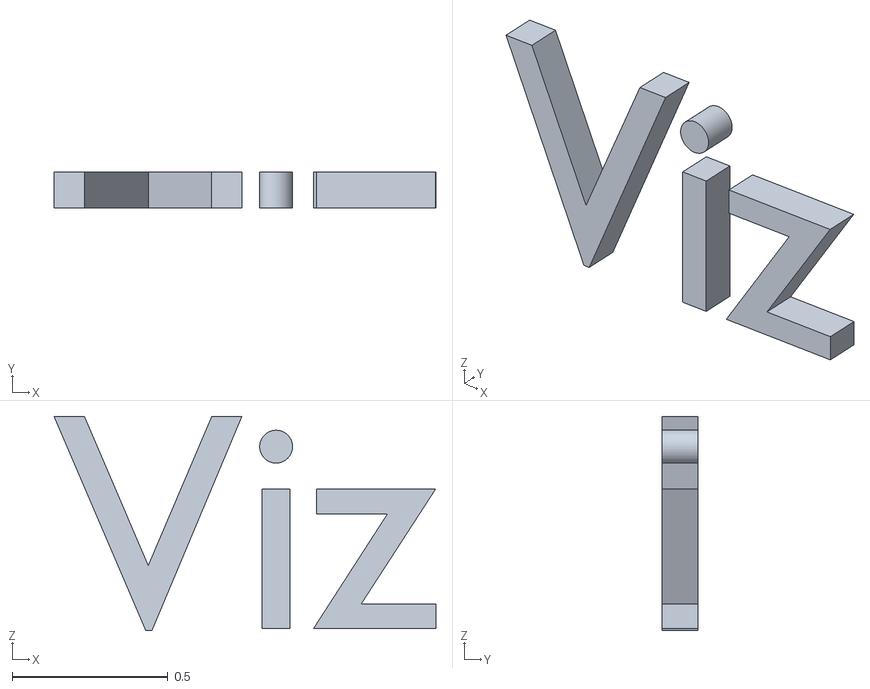
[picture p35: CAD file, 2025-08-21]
Detector/ros_catkin_ws/src/rviz/image_src/Viz.stl
1.23 x 0.115 x 0.688

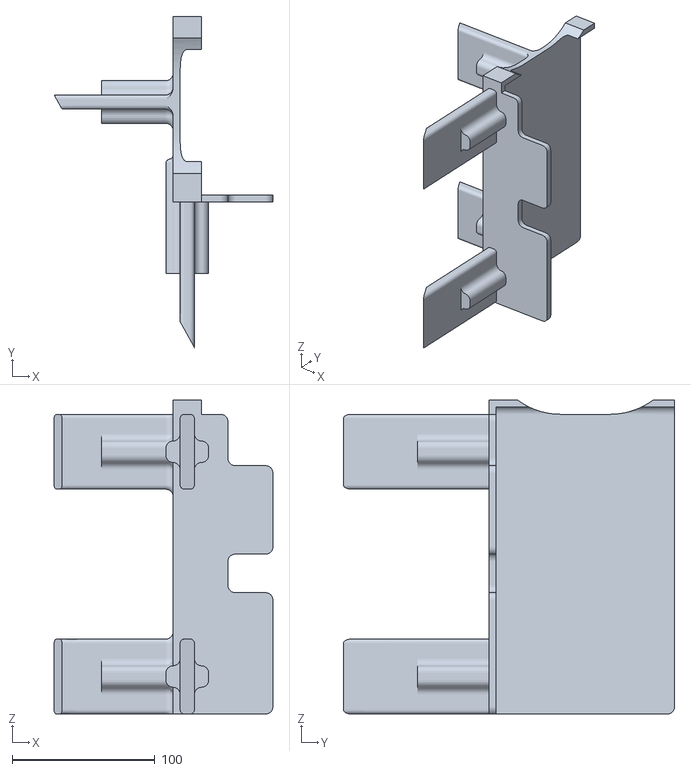
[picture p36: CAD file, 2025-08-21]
3D Models/Table Support (for exhibition).stl
153.3 x 232.0 x 220.0

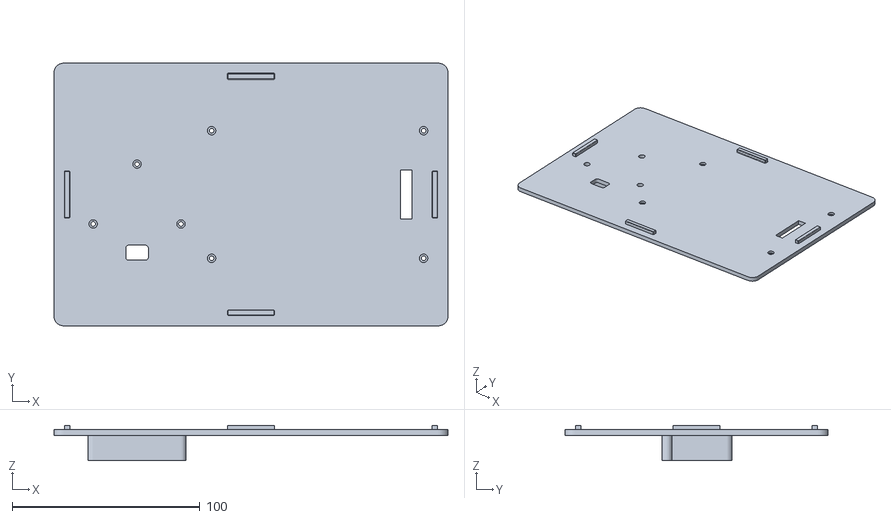
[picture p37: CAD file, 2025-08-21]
3D Models/The Lid.stl
210.0 x 140.0 x 18.8

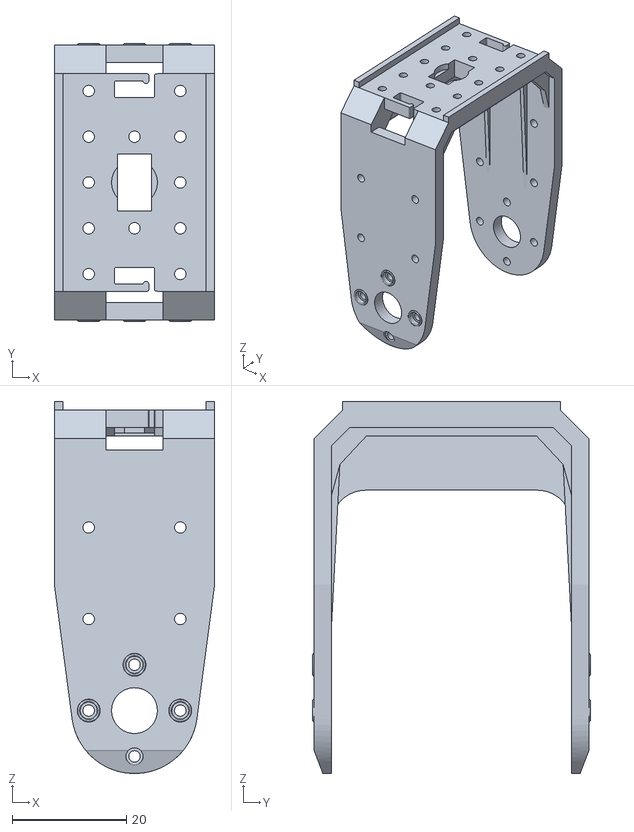
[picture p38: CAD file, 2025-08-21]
Detector/ros_catkin_ws/src/rviz/src/test/meshes/F4.stl
28.0 x 48.5 x 65.0

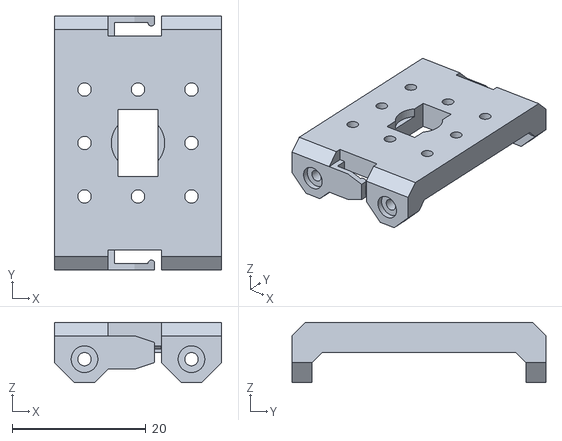
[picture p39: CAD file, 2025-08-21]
Detector/ros_catkin_ws/src/rviz/src/test/meshes/F3.stl
25.0 x 38.0 x 9.00

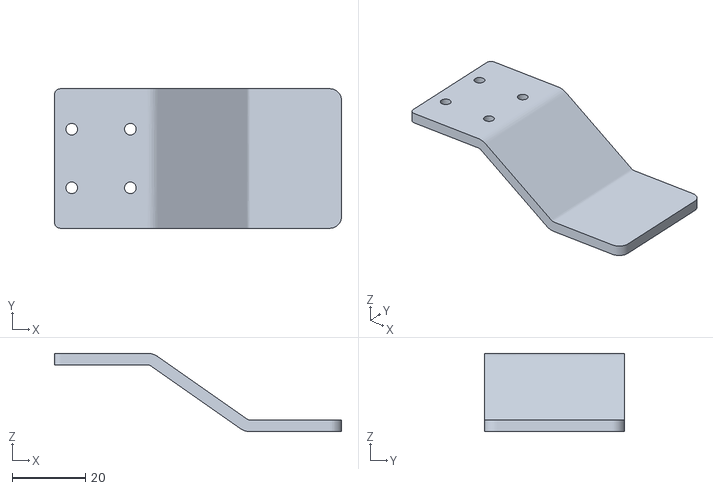
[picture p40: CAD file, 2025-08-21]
Detector/ros_catkin_ws/src/rviz/src/test/meshes/finger.stl
78.3 x 38.1 x 21.4

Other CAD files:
3D Models/The Box V2.stl
Detector/ros_catkin_ws/src/rviz/src/test/meshes/valid_ascii.stl
Detector/ros_catkin_ws/src/rviz/src/test/meshes/ax12_box.stl
Detector/ros_catkin_ws/src/rviz/src/test/meshes/invalid_extra.stl
Detector/ros_catkin_ws/src/rviz/src/test/meshes/invalid.stl
Detector/ros_catkin_ws/src/rviz/src/test/meshes/invalid_short.stl
Detector/ros_catkin_ws/src/rviz/image_src/R.blend
Detector/ros_catkin_ws/src/rviz/image_src/RViz.blend
Detector/ros_catkin_ws/src/rviz/image_src/Viz.blend
Detector/ros_catkin_ws/src/rviz/src/test/meshes/16bit_vs_32bit_should_fail.stl
Detector/ros_catkin_ws/src/rviz/src/test/meshes/F10.stl
Detector/ros_catkin_ws/src/rviz/src/test/meshes/F2.stl

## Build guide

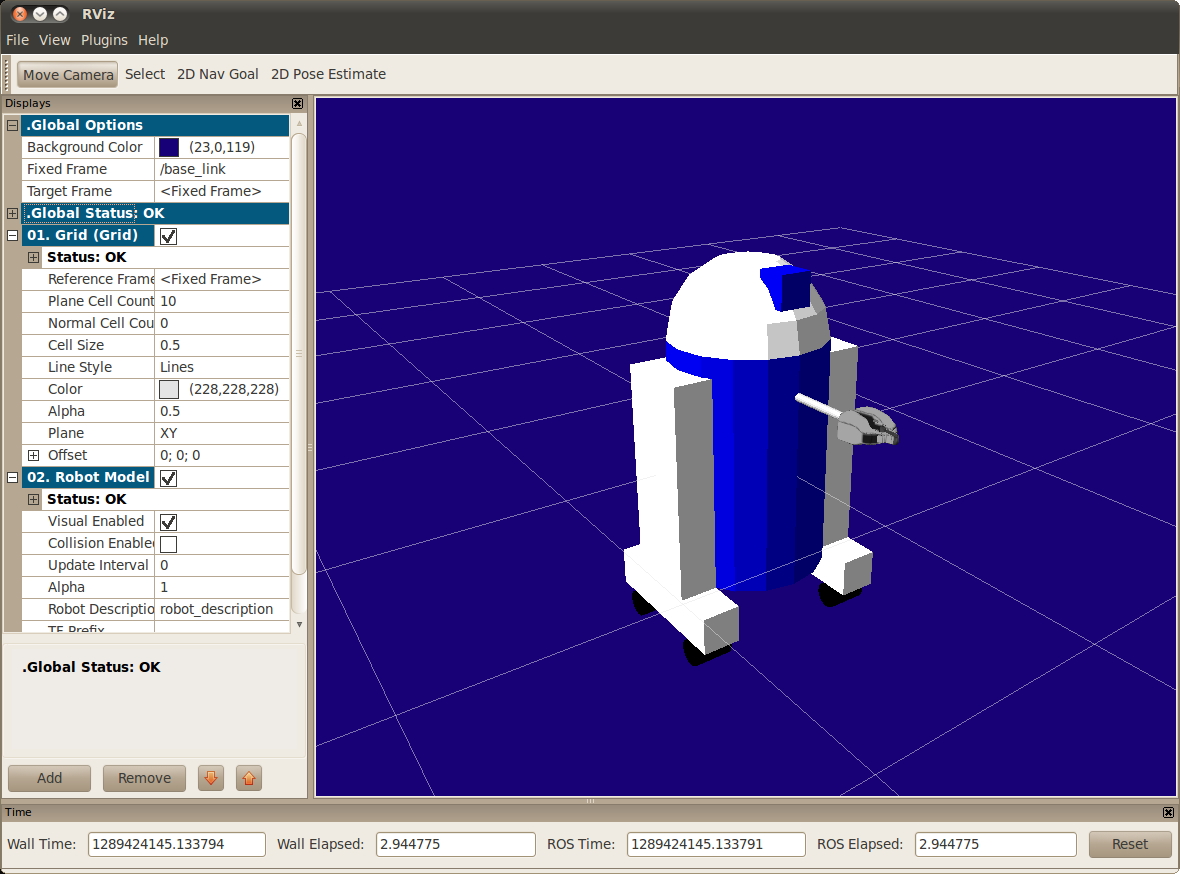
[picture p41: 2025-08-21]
Detector/ros_catkin_ws/src/urdf_tutorial/images/visual.png

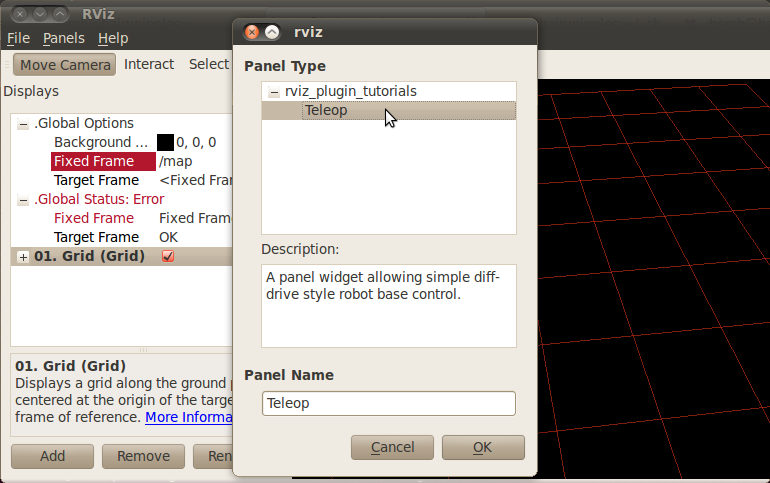
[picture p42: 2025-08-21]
Detector/ros_catkin_ws/src/visualization_tutorials/rviz_plugin_tutorials/src/doc/teleop_plugin.png

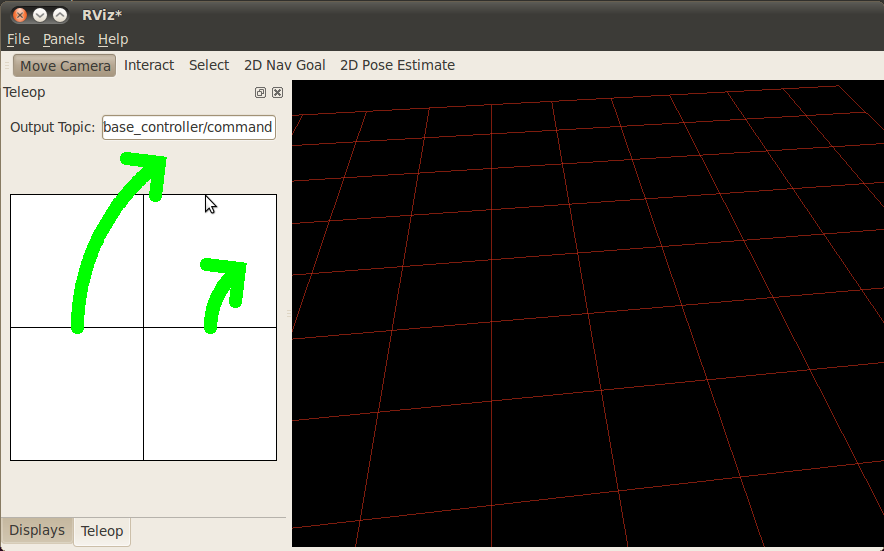
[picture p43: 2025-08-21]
Detector/ros_catkin_ws/src/visualization_tutorials/rviz_plugin_tutorials/src/doc/teleop_in_rviz.png

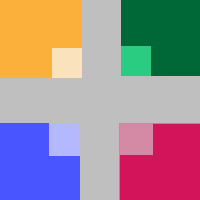
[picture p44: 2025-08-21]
Detector/ros_catkin_ws/src/ros_tutorials/turtlesim/images/palette.png

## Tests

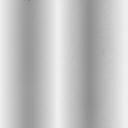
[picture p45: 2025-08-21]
Detector/ros_catkin_ws/src/rviz/src/test/meshes/kitchen/images/texture4.jpg

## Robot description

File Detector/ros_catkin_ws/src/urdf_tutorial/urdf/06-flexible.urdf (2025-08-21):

<?xml version="1.0"?>
<robot name="visual">

<material name="blue">
    <color rgba="0 0 0.8 1"/>
  </material>
  <material name="black">
    <color rgba="0 0 0 1"/>
  </material>
  <material name="white">
    <color rgba="1 1 1 1"/>
  </material>

  <link name="base_link">
    <visual>
      <geometry>
        <cylinder length="0.6" radius="0.2"/>
      </geometry>
      <material name="blue"/>
    </visual>
  </link>

  <link name="right_leg">
    <visual>
      <geometry>
        <box size="0.6 0.1 0.2"/>
      </geometry>
      <origin rpy="0 1.57075 0" xyz="0 0 -0.3"/>
      <material name="white"/>
    </visual>
  </link>

  <joint name="base_to_right_leg" type="fixed">
    <parent link="base_link"/>
    <child link="right_leg"/>
    <origin xyz="0 -0.22 0.25"/>
  </joint>

  <link name="right_base">
    <visual>
      <geometry>
        <box size="0.4 0.1 0.1"/>
      </geometry>
      <material name="white"/>
    </visual>
  </link>

  <joint name="right_base_joint" type="fixed">
    <parent link="right_leg"/>
    <child link="right_base"/>
    <origin xyz="0 0 -0.6"/>
  </joint>

  <link name="right_front_wheel">
    <visual>
      <origin rpy="1.57075 0 0" xyz="0 0 0"/>
      <geometry>
        <cylinder length="0.1" radius="0.035"/>
      </geometry>
      <material name="black"/>
      <origin rpy="0 0 0" xyz="0 0 0"/>
    </visual>
  </link>
  <joint name="right_front_wheel_joint" type="continuous">
    <axis rpy="0 0 0" xyz="0 1 0"/>
    <parent link="right_base"/>
    <child link="right_front_wheel"/>
    <origin rpy="0 0 0" xyz="0.133333333333 0 -0.085"/>
  </joint>

  <link name="right_back_wheel">
    <visual>
      <origin rpy="1.57075 0 0" xyz="0 0 0"/>
      <geometry>
        <cylinder length="0.1" radius="0.035"/>
      </geometry>
      <material name="black"/>
    </visual>
  </link>
  <joint name="right_back_wheel_joint" type="continuous">
    <axis rpy="0 0 0" xyz="0 1 0"/>
    <parent link="right_base"/>
    <child link="right_back_wheel"/>
    <origin rpy="0 0 0" xyz="-0.133333333333 0 -0.085"/>
  </joint>

  <link name="left_leg">
    <visual>
      <geometry>
        <box size="0.6 0.1 0.2"/>
      </geometry>
      <origin rpy="0 1.57075 0" xyz="0 0 -0.3"/>
      <material name="white"/>
    </visual>
  </link>

  <joint name="base_to_left_leg" type="fixed">
    <parent link="base_link"/>
    <child link="left_leg"/>
    <origin xyz="0 0.22 0.25"/>
  </joint>

  <link name="left_base">
    <visual>
      <geometry>
        <box size="0.4 0.1 0.1"/>
      </geometry>
      <material name="white"/>
    </visual>
  </link>

  <joint name="left_base_joint" type="fixed">
    <parent link="left_leg"/>
    <child link="left_base"/>
    <origin xyz="0 0 -0.6"/>
  </joint>

  <link name="left_front_wheel">
    <visual>
      <origin rpy="1.57075 0 0" xyz="0 0 0"/>
      <geometry>
        <cylinder length="0.1" radius="0.035"/>
      </geometry>
      <material name="black"/>
    </visual>
  </link>
  <joint name="left_front_wheel_joint" type="continuous">
    <axis rpy="0 0 0" xyz="0 1 0"/>
    <parent link="left_base"/>
    <child link="left_front_wheel"/>
    <origin rpy="0 0 0" xyz="0.133333333333 0 -0.085"/>
  </joint>

  <link name="left_back_wheel">
    <visual>
      <origin rpy="1.57075 0 0" xyz="0 0 0"/>
      <geometry>
        <cylinder length="0.1" radius="0.035"/>
      </geometry>
      <material name="black"/>
    </visual>
  </link>
  <joint name="left_back_wheel_joint" type="continuous">
    <axis rpy="0 0 0" xyz="0 1 0"/>
    <parent link="left_base"/>
    <child link="left_back_wheel"/>
    <origin rpy="0 0 0" xyz="-0.133333333333 0 -0.085"/>
  </joint>

  <joint name="gripper_extension" type="prismatic">
    <parent link="base_link"/>
    <child link="gripper_pole"/>
    <limit effort="1000.0" lower="-0.38" upper="0" velocity="0.5"/>
    <origin rpy="0 0 0" xyz="0.19 0 0.2"/>
  </joint>

  <link name="gripper_pole">
    <visual>
      <geometry>
        <cylinder length="0.2" radius="0.01"/>
      </geometry>
      <origin rpy="0 1.57075 0 " xyz="0.1 0 0"/>
    </visual>
  </link>

  <joint name="left_gripper_joint" type="revolute">
    <axis xyz="0 0 1"/>
    <limit effort="1000.0" lower="0.0" upper="0.548" velocity="0.5"/>
    <origin rpy="0 0 0" xyz="0.2 0.01 0"/>
    <parent link="gripper_pole"/>
    <child link="left_gripper"/>
  </joint>

  <link name="left_gripper">
    <visual>
      <origin rpy="0.0 0 0" xyz="0 0 0"/>
      <geometry>
        <mesh filename="package://urdf_tutorial/meshes/l_finger.dae"/>
      </geometry>
    </visual>
  </link>

  <joint name="left_tip_joint" type="fixed">
    <parent link="left_gripper"/>
    <child link="left_tip"/>
  </joint>

  <link name="left_tip">
    <visual>
      <origin rpy="0.0 0 0" xyz="0.09137 0.00495 0"/>
      <geometry>
        <mesh filename="package://urdf_tutorial/meshes/l_finger_tip.dae"/>
      </geometry>
    </visual>
  </link>
  <joint name="right_gripper_joint" type="revolute">
    <axis xyz="0 0 -1"/>
    <limit effort="1000.0" lower="0.0" upper="0.548" velocity="0.5"/>
    <origin rpy="0 0 0" xyz="0.2 -0.01 0"/>
    <parent link="gripper_pole"/>
    <child link="right_gripper"/>
  </joint>

  <link name="right_gripper">
    <visual>
      <origin rpy="-3.1415 0 0" xyz="0 0 0"/>
      <geometry>
        <mesh filename="package://urdf_tutorial/meshes/l_finger.dae"/>
      </geometry>
    </visual>
  </link>

  <joint name="right_tip_joint" type="fixed">
    <parent link="right_gripper"/>
    <child link="right_tip"/>
  </joint>

  <link name="right_tip">
    <visual>
      <origin rpy="-3.1415 0 0" xyz="0.09137 0.00495 0"/>
      <geometry>
        <mesh filename="package://urdf_tutorial/meshes/l_finger_tip.dae"/>
      </geometry>
    </visual>
  </link>

  <link name="head">
    <visual>
      <geometry>
        <sphere radius="0.2"/>
      </geometry>
      <material name="white"/>
    </visual>
  </link>
  <joint name="head_swivel" type="continuous">
    <parent link="base_link"/>
    <child link="head"/>
    <axis xyz="0 0 1"/>
    <origin xyz="0 0 0.3"/>
  </joint>

  <link name="box">
    <visual>
      <geometry>
        <box size="0.08 0.08 0.08"/>
      </geometry>
      <material name="blue"/>
    </visual>
  </link>

  <joint name="tobox" type="fixed">
    <parent link="head"/>
    <child link="box"/>
    <origin xyz="0.1814 0 0.1414"/>
  </joint>
</robot>

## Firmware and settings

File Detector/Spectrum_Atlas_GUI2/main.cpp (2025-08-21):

#include <cstdlib>
#include <cstdio>
#include <cstring>
#include <string>
#include <sstream>
#include <unistd.h>        // execvp

#include <QApplication>
#include <QTimer>
#include <ros/ros.h>

#include "mainwindow.h"

/* ---------- Change this to switch to Noetic or others ---------- */
static const char* ROS_ROOT_PATH = "/opt/ros/melodic";
static const char* ENV_READY     = "ROS_GUI_ENV_READY";

/* Can `rospack` find `rviz`? */
static bool rvizFound()
{
    FILE* pipe = popen("rospack find rviz 2>/dev/null", "r");
    if (!pipe) return false;
    char buf[8];
    bool ok = (fgets(buf, sizeof(buf), pipe) != nullptr);
    pclose(pipe);
    return ok;
}

/* Prepend environment variables like PATH and LD_LIBRARY_PATH */
static void prependEnv(const char* key, const std::string& prefix)
{
    const char* old = getenv(key);
    std::string val = prefix;
    if (old && *old) val += ":" + std::string(old);
    setenv(key, val.c_str(), 1);
}

/* --------- Prepare ROS environment and re-execute if needed --------- */
static void prepareEnvAndReexec(int argc, char** argv)
{
    if (getenv(ENV_READY) || rvizFound())
        return;

    /* Melodic base paths */
    prependEnv("PATH", std::string(ROS_ROOT_PATH) + "/bin");
    prependEnv("PYTHONPATH",
               std::string(ROS_ROOT_PATH) + "/lib/python2.7/dist-packages");
    prependEnv("LD_LIBRARY_PATH",
               std::string(ROS_ROOT_PATH) + "/lib:" +
               std::string(ROS_ROOT_PATH) + "/lib/arm-linux-gnueabihf");
    prependEnv("PKG_CONFIG_PATH",
               std::string(ROS_ROOT_PATH) + "/lib/pkgconfig:" +
               std::string(ROS_ROOT_PATH) + "/share/pkgconfig");
    prependEnv("ROS_PACKAGE_PATH",
               std::string(ROS_ROOT_PATH) + "/share:" +
               std::string(ROS_ROOT_PATH) + "/stacks");

    setenv("ROS_ROOT",
           (std::string(ROS_ROOT_PATH) + "/share/ros").c_str(), 1);
    setenv("ROS_ETC_DIR",
           (std::string(ROS_ROOT_PATH) + "/etc/ros").c_str(), 1);
    setenv("ROS_MASTER_URI", "http://localhost:11311", 0);

    /* Remove ROS 2 paths */
    if (const char* raw = getenv("LD_LIBRARY_PATH")) {
        std::stringstream ss(raw); std::string seg, clean;
        while (std::getline(ss, seg, ':')) {
            if (seg.find("/opt/ros/foxy")   != std::string::npos ||
                seg.find("/opt/ros/humble") != std::string::npos ||
                seg.find("/opt/ros/iron")   != std::string::npos) continue;
            if (!seg.empty()) clean += seg + ":";
        }
        std::string lead = std::string(ROS_ROOT_PATH) + "/lib:" +
                           std::string(ROS_ROOT_PATH) + "/lib/arm-linux-gnueabihf";
        clean = lead + ":" + clean;
        if (!clean.empty() && clean.back() == ':') clean.pop_back();
        setenv("LD_LIBRARY_PATH", clean.c_str(), 1);
    }

    setenv(ENV_READY, "1", 1);
    fprintf(stderr, "[INFO] Environment prepared, re–exec...\n");
    execvp(argv[0], argv);
    perror("execvp failed");
    std::exit(EXIT_FAILURE);
}

/* ---------------- main ---------------- */
int main(int argc, char** argv)
{
    prepareEnvAndReexec(argc, argv);

    ros::init(argc, argv, "qt_ros_gui");
    QApplication app(argc, argv);

    MainWindow w; w.show();

    QTimer rosTimer;
    QObject::connect(&rosTimer, &QTimer::timeout, []{ ros::spinOnce(); });
    rosTimer.start(30);

    return app.exec();
}
